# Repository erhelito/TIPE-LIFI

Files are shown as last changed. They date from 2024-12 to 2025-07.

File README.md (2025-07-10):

# TIPE LIFI
This is a school project in which we first created an operating communication system through light in ambient light conditions and without optic fiber. It includes multiple corrective systems, allowing us to use the system in a wide range of conditions. Then, we studied the performance of the system, in terms of length of transmission, thanks to the study of our laser dispersion.

For more information, please visit my website: https://www.erhelczc.wordpress.com

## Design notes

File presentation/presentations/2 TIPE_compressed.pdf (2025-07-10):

# COMMUNICATION PAR LASER À GRANDE DISTANCE

CAYZAC Erhel 32242

01

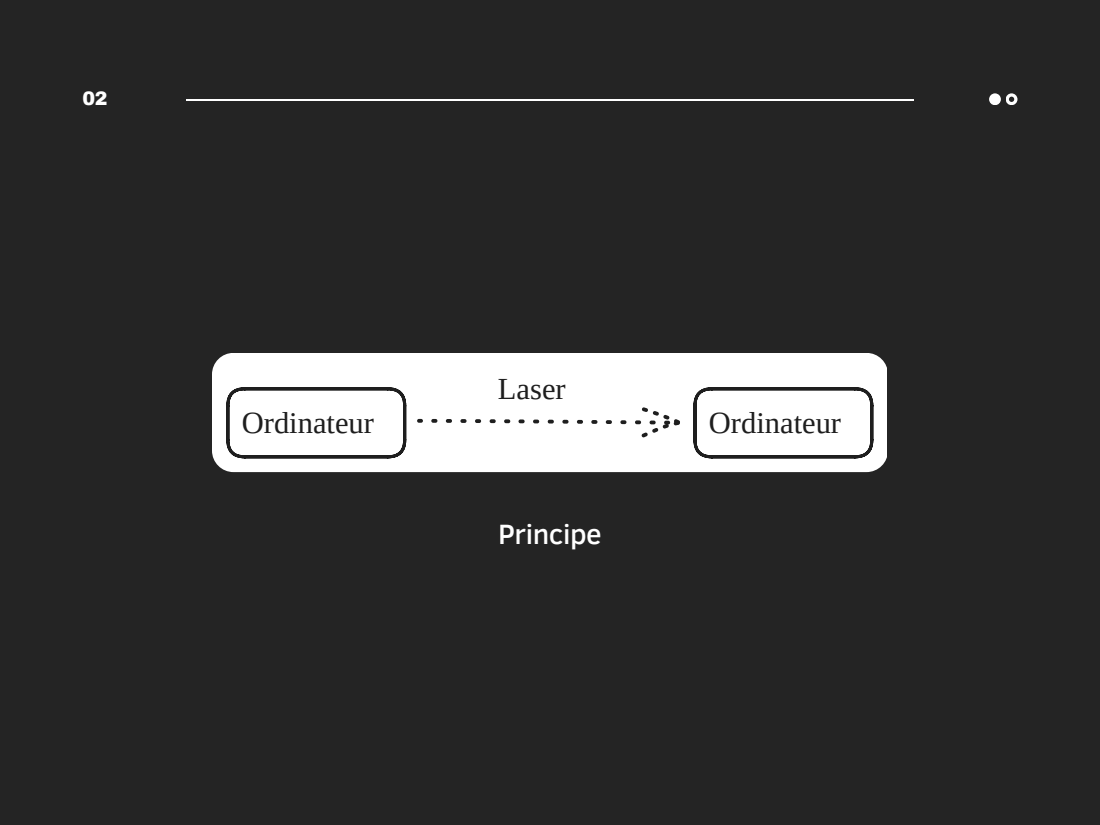
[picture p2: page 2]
Ordinateur; Laser; Principe

03

# POURQUOI ?

Haut débit de transmission Liaison sans fil sécurisée Lien analogique / numérique

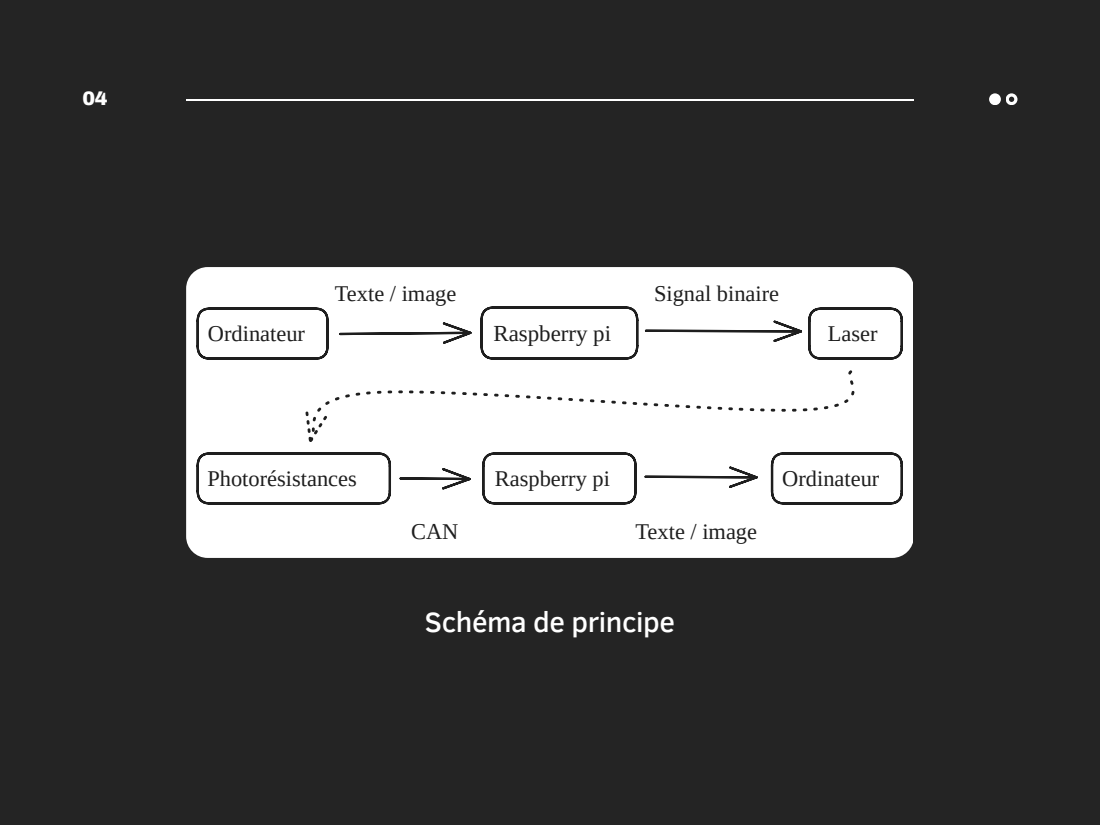
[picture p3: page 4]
Ordinateur; Texte / image; Signal binaire; CAN; Raspberry pi; Laser; Photorésistances

Schéma de principe

05

I PREMIER PROTOTYPE | PLAN

Électronique, transmission,
blocages, limitations

II AMÉLIORATION DU
MODÈLE
Capteurs, codes correcteurs, vitesse d’émission

III LIMITES, ÉTUDE
THÉORIQUE
Analyse théorique du projet proposé

06

# UN PREMIER PROTOTYPE

1.Émission
2.Protocole de communication 3.Réception
4.Problèmes rencontrés

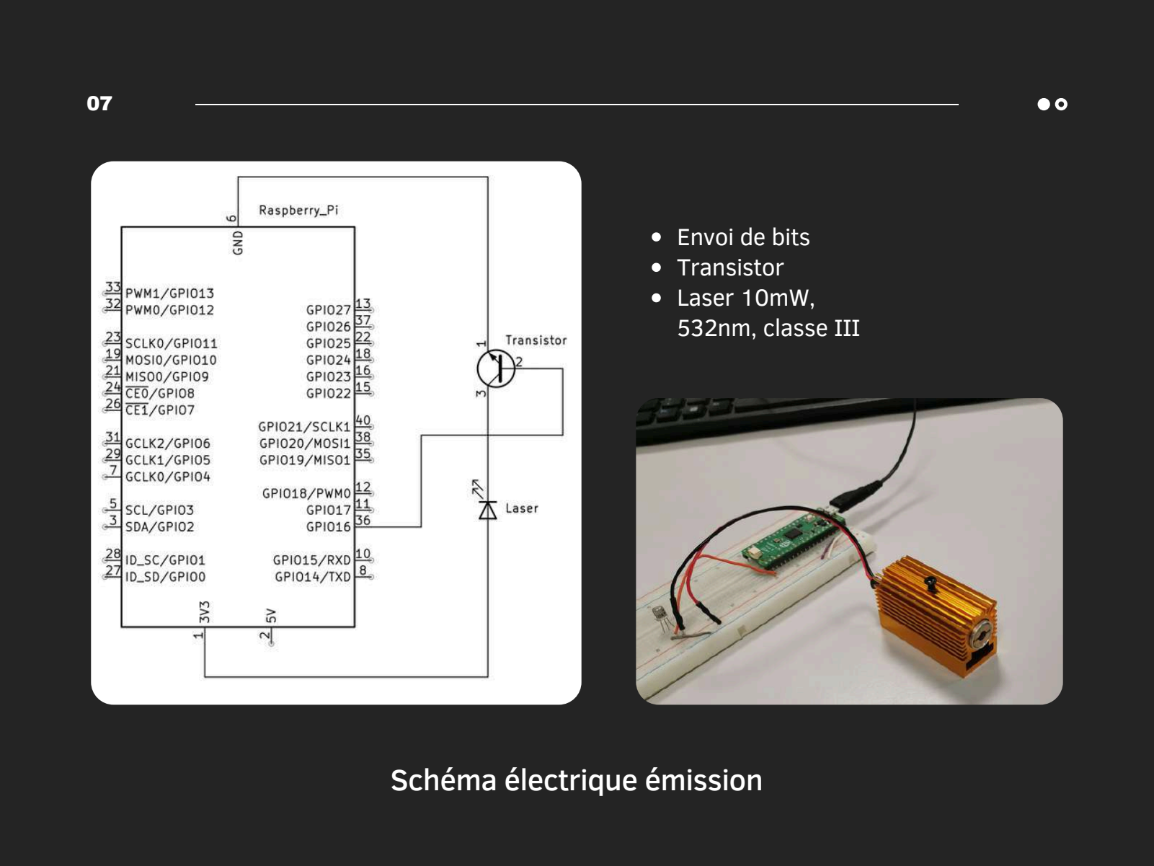
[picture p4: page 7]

07

Schéma électrique émission

Envoi de bits
Transistor
Laser 10mW,
532nm, classe III

08

Émission : “10110”

Réception : “...00010110000...”

### DÉTECTER L’ÉMISSION

Signal brut : “10110”

Émission : “1101101”

Réception : “...0001101101000...”

09

Schéma électrique réception

Diviseurs de tension
CAN
Comparaison
Seuil

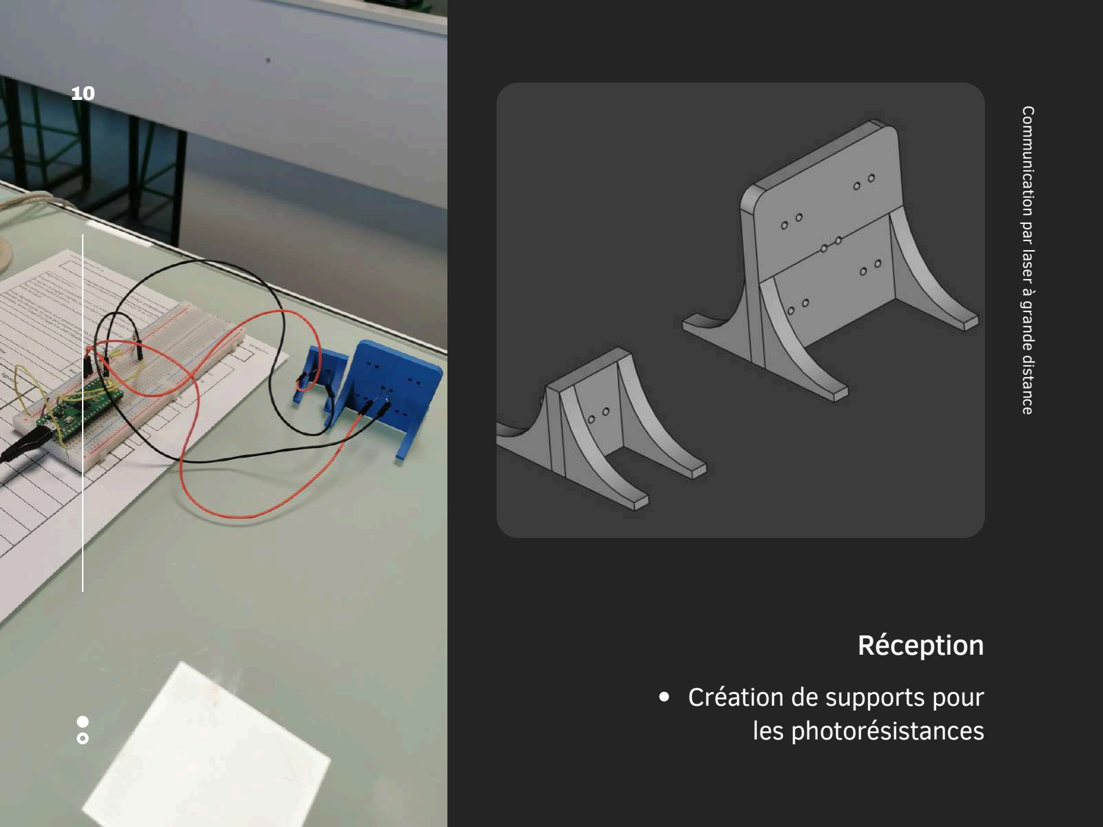
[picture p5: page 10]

1

0
Communication par laser à grande distance

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
r les photorésistances

11

# PREMIÈRES LIMITATIONS

Non adaptabilité (seuil)
Non linéarité (photorésistances) Manque de fiabilité (lenteur Raspberry)

12

# SECOND PROTOTYPE

1.Phototransistors
2.Traitement différé
3.Seuil variable
4.Gestion des erreurs

13

Schéma électrique réception

14

# SEUIL DE DÉTECTION

Comparaison des données
capteur
Partitionnement des données

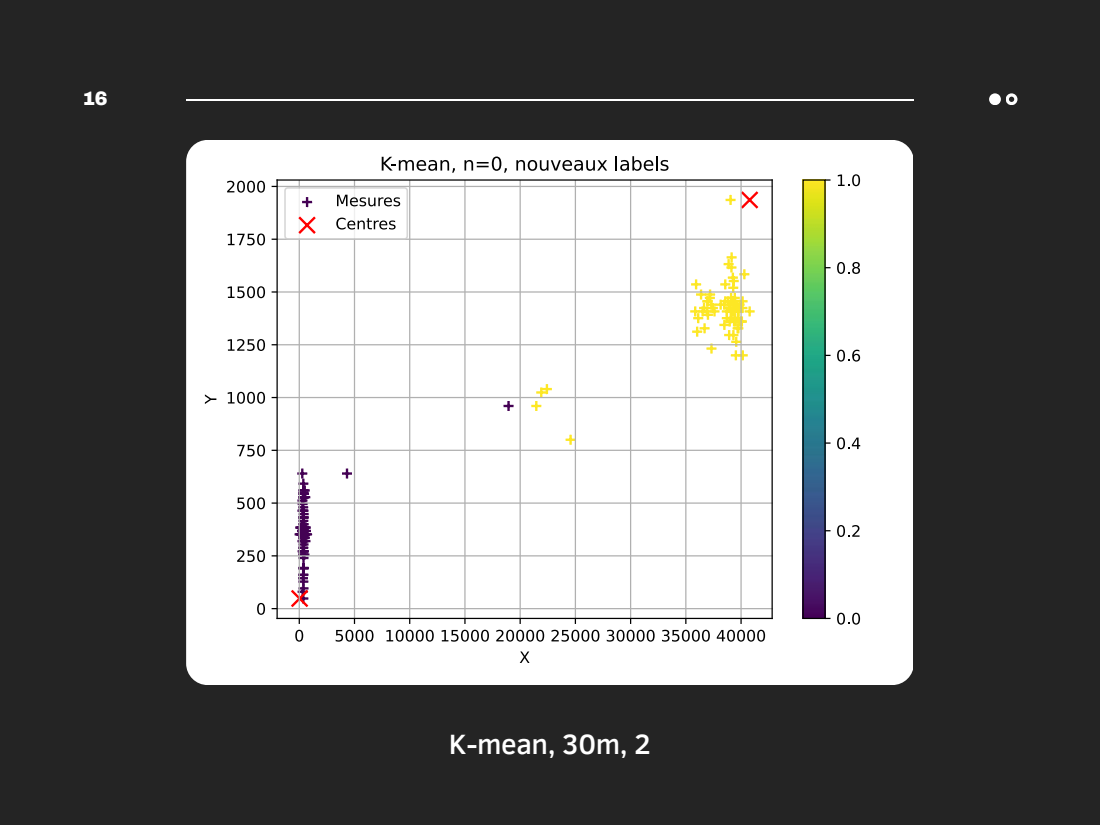
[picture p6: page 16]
K-mean, 30m, 2

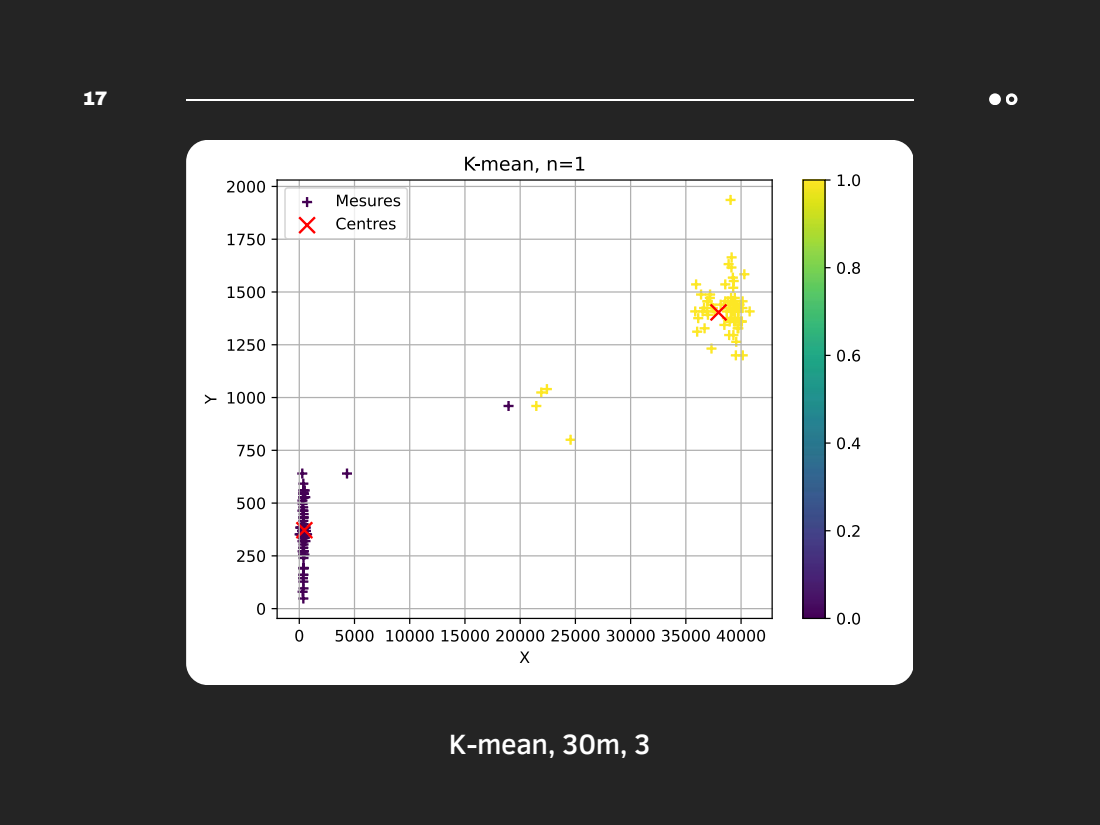
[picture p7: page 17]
K-mean, 30m, 3

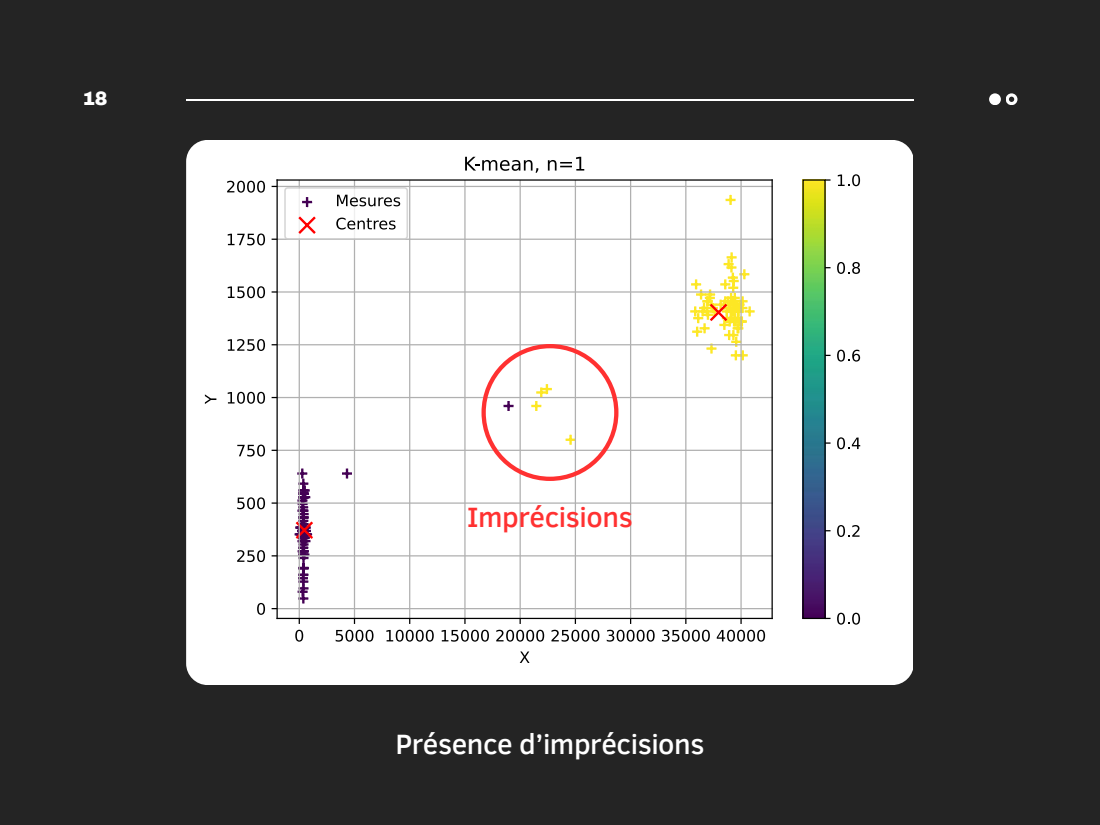
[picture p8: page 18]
Présence d’imprécisions; Imprécisions

19

# TRAITEMENT DES ERREURS

Critère de Shannon :
1.Filtrage par moyenne glissante

Code correcteur de Hamming : 1.Ajout de bits de parité
2.Vérification de la cohérence 3.Correction

1

9

Communication par laser à grande distance

21

# DIODE LASER

Modèle du faisceau gaussien Étude de l’évolution de l’irradiance lumineuse

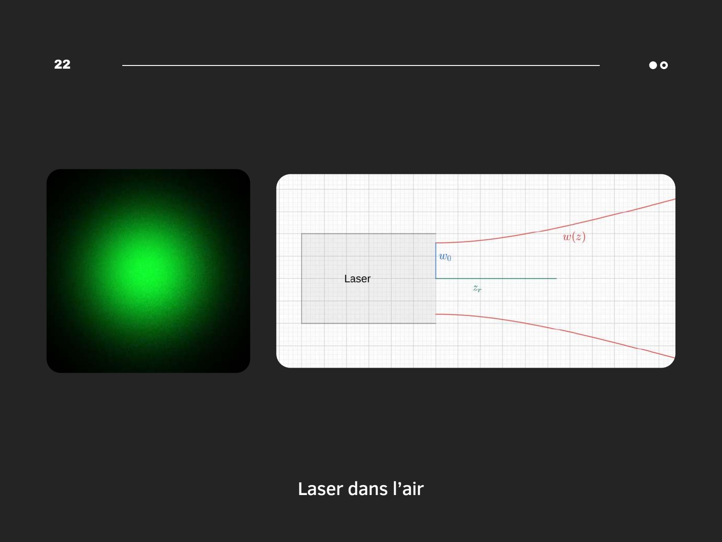
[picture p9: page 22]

Laser dans l’air

22

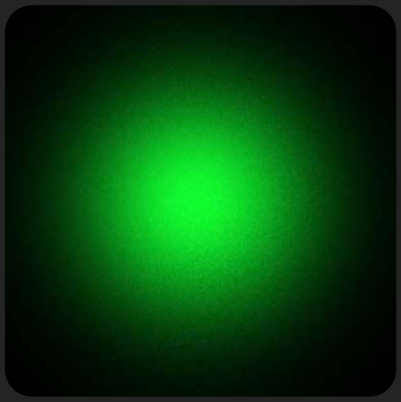
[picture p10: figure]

Irradiance du faisceau Gaussien

23

Divergence et longueur de Rayleigh

24

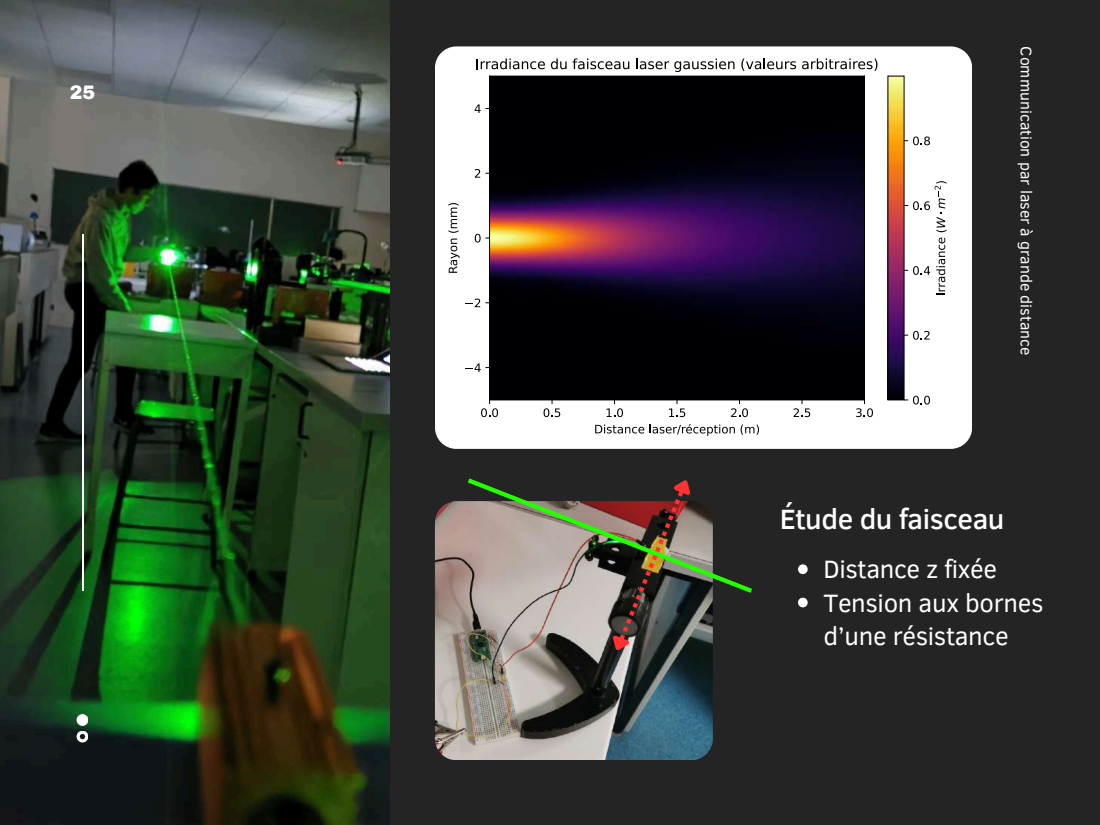
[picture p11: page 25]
fais; Dis; fix; sio; sis

Communication par laser à grande distance

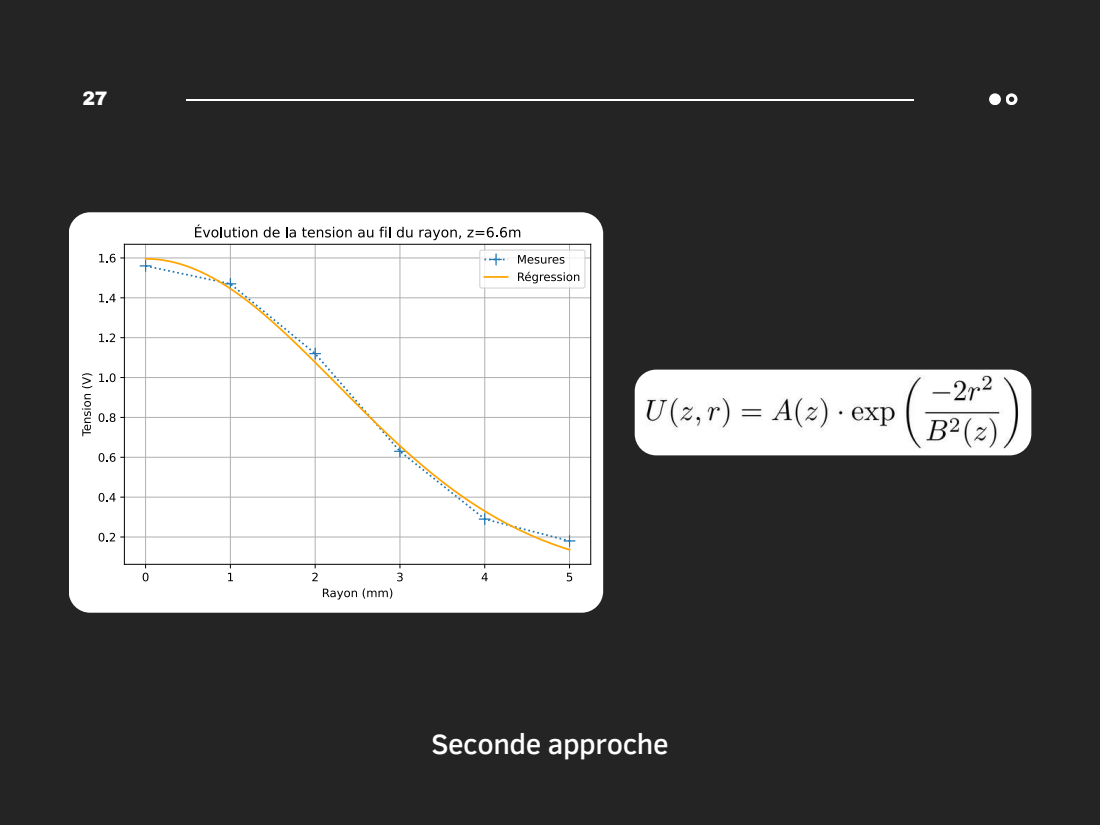
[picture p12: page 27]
Seconde approche

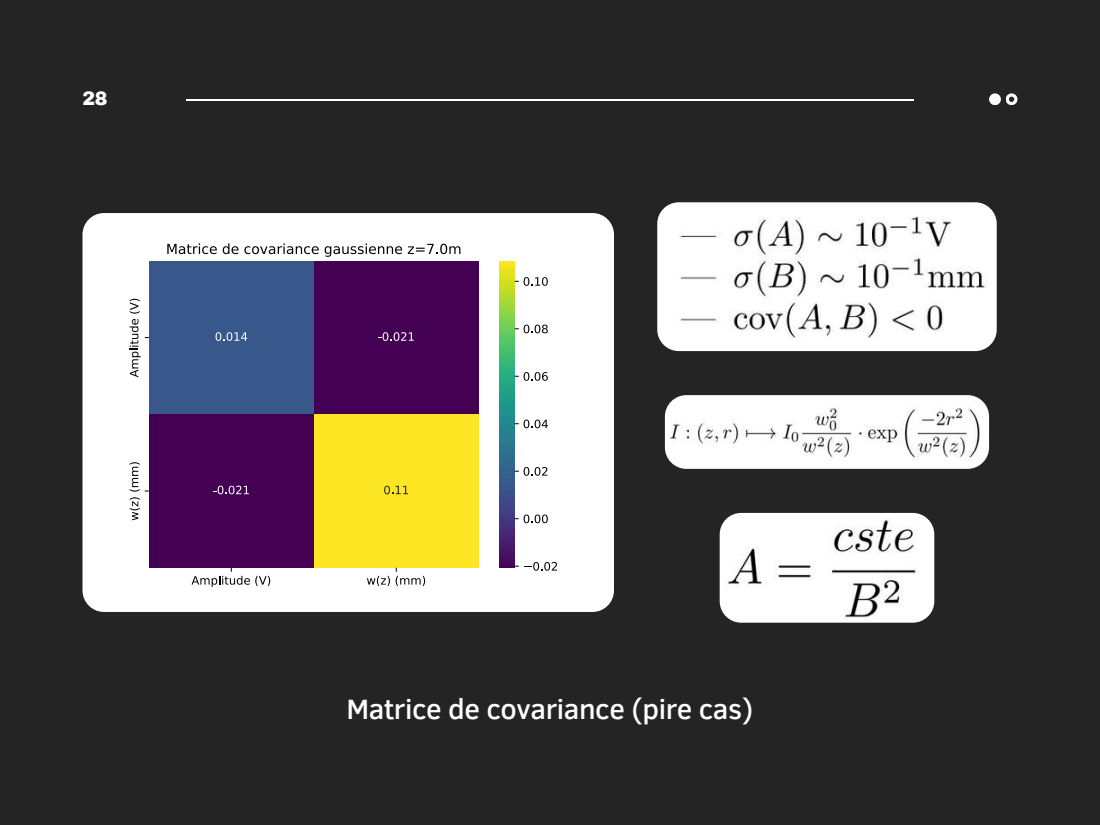
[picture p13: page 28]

Matrice de covariance (pire cas)

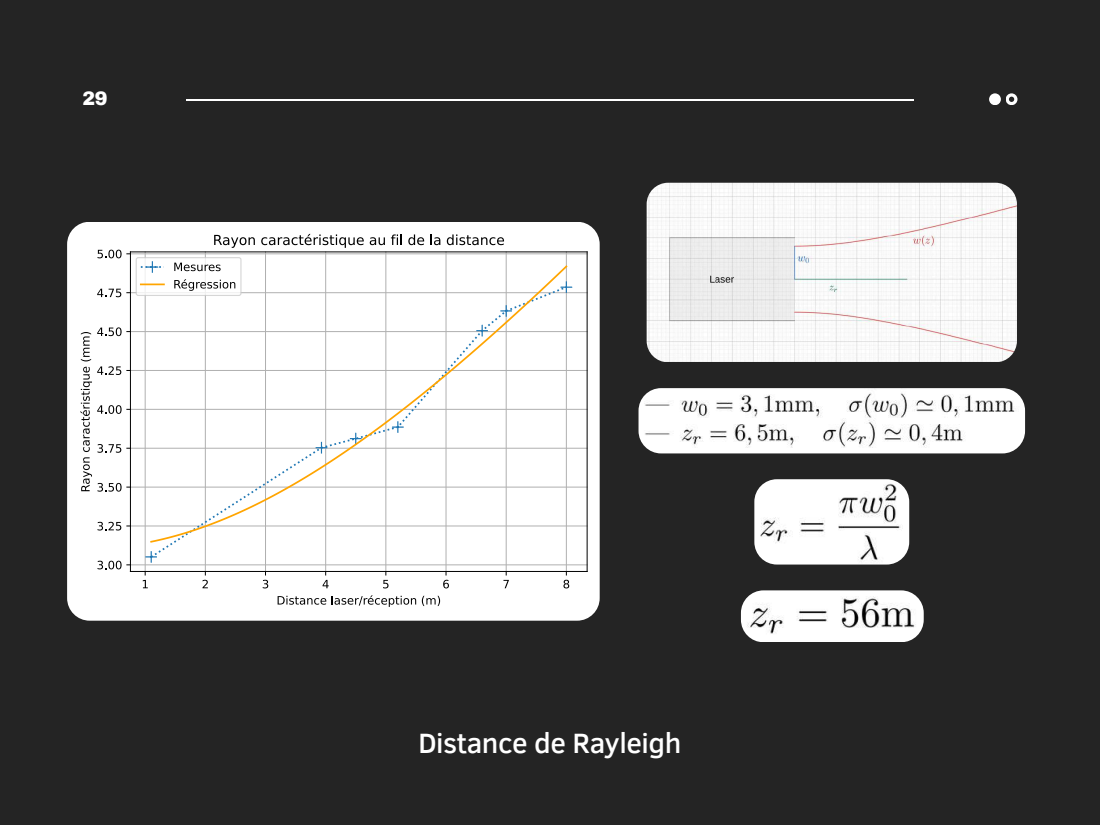
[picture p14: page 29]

Distance de Rayleigh

30

# CONCLUSION

Système fonctionnel
Adaptation à la luminosité Correction des erreurs
Débit peu élevé (Python)

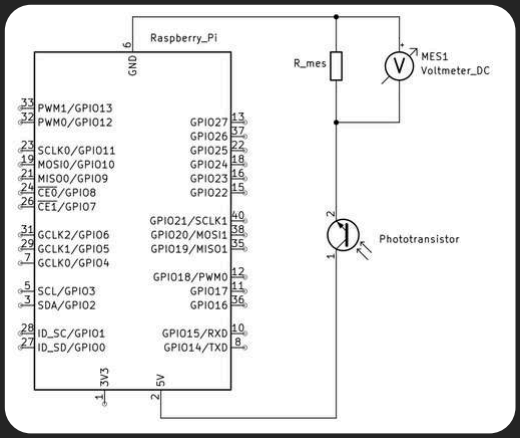
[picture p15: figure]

Annexe : Protocole faisceau Gaussien

31

32

# ANNEXE : PHOTORÉSISTANCE

Facile d’utilisation
Non linéaire

# Tracé de la caractéristique

PROTOCOLE :
Pont diviseur de
tension
Éclairement constant

33

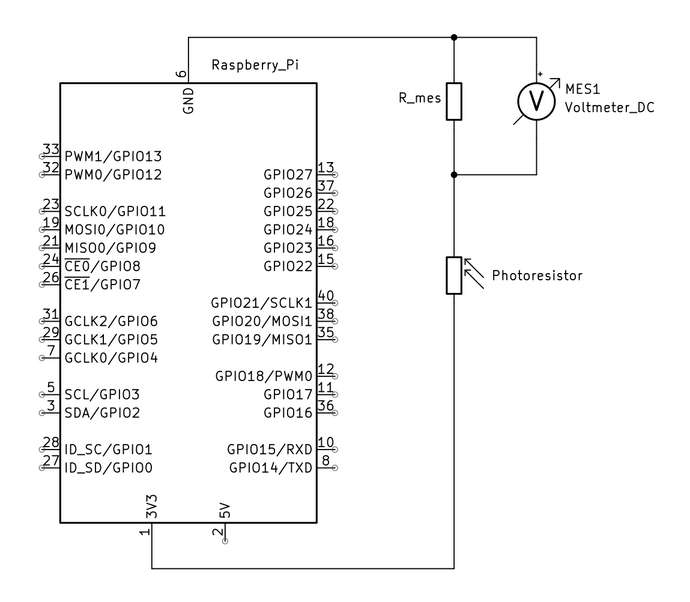
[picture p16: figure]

Schéma électrique

34

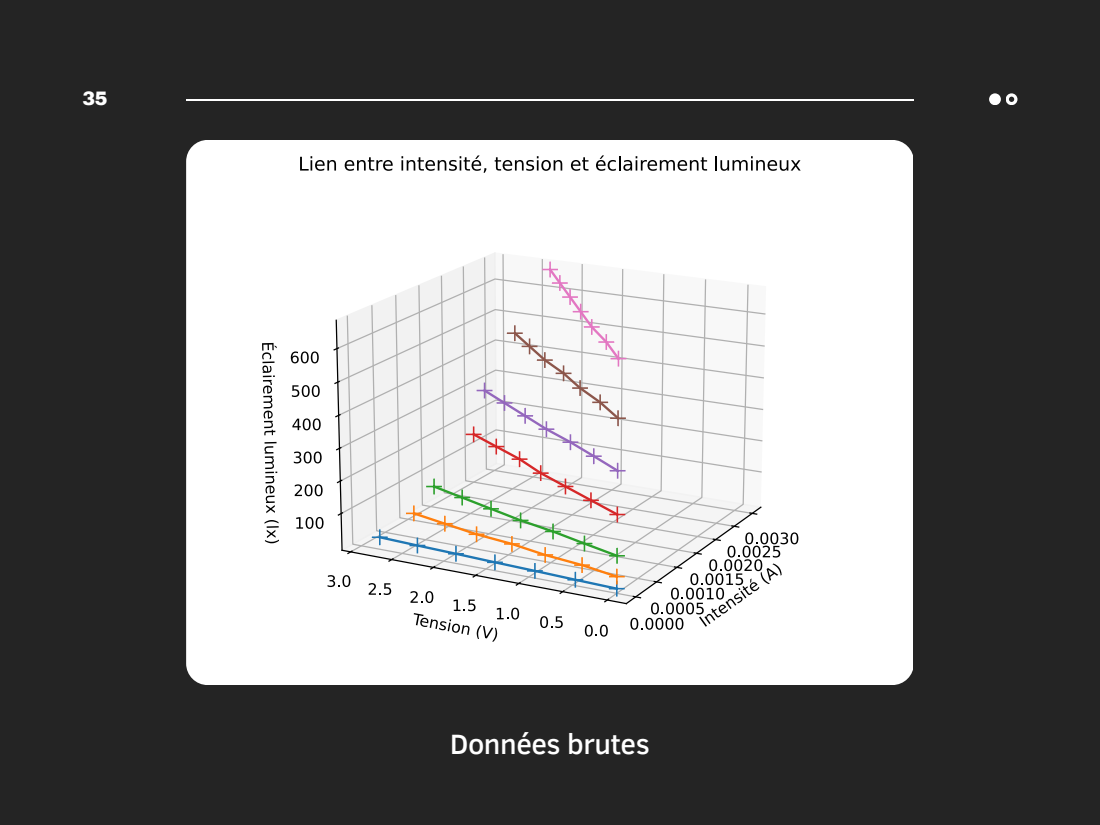
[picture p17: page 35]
Données brutes

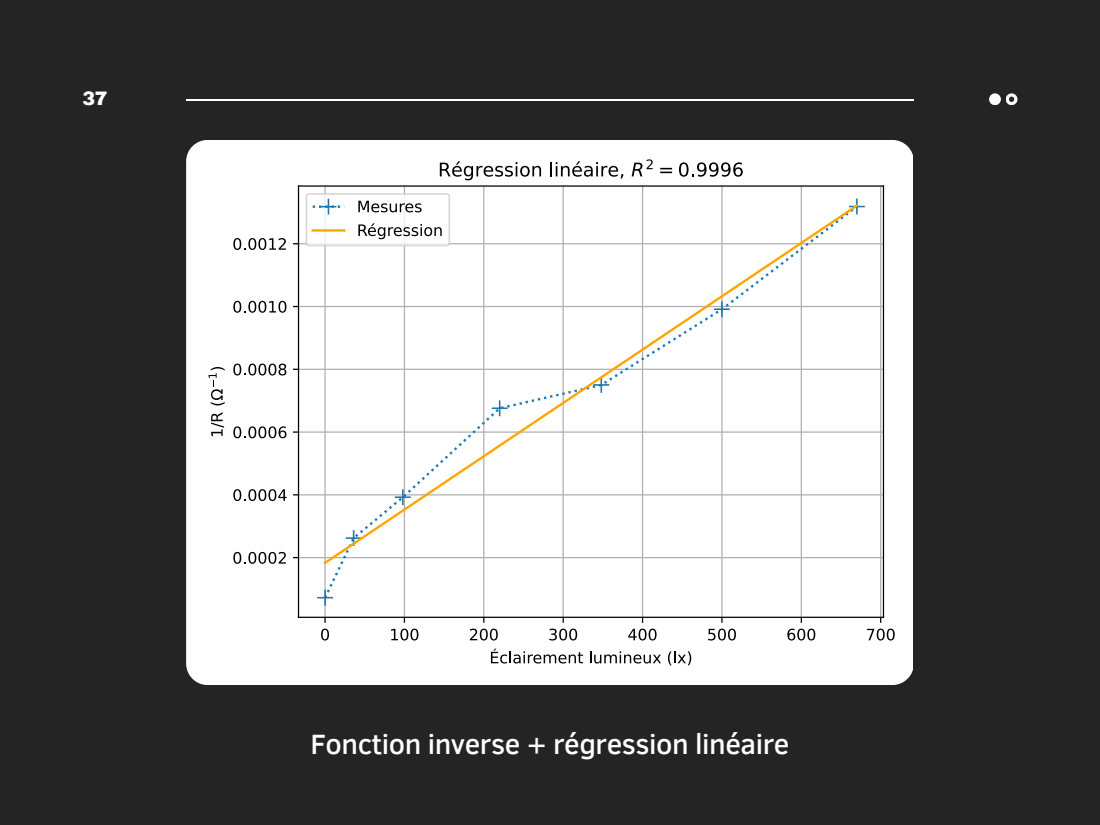
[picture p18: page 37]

Fonction inverse + régression linéaire

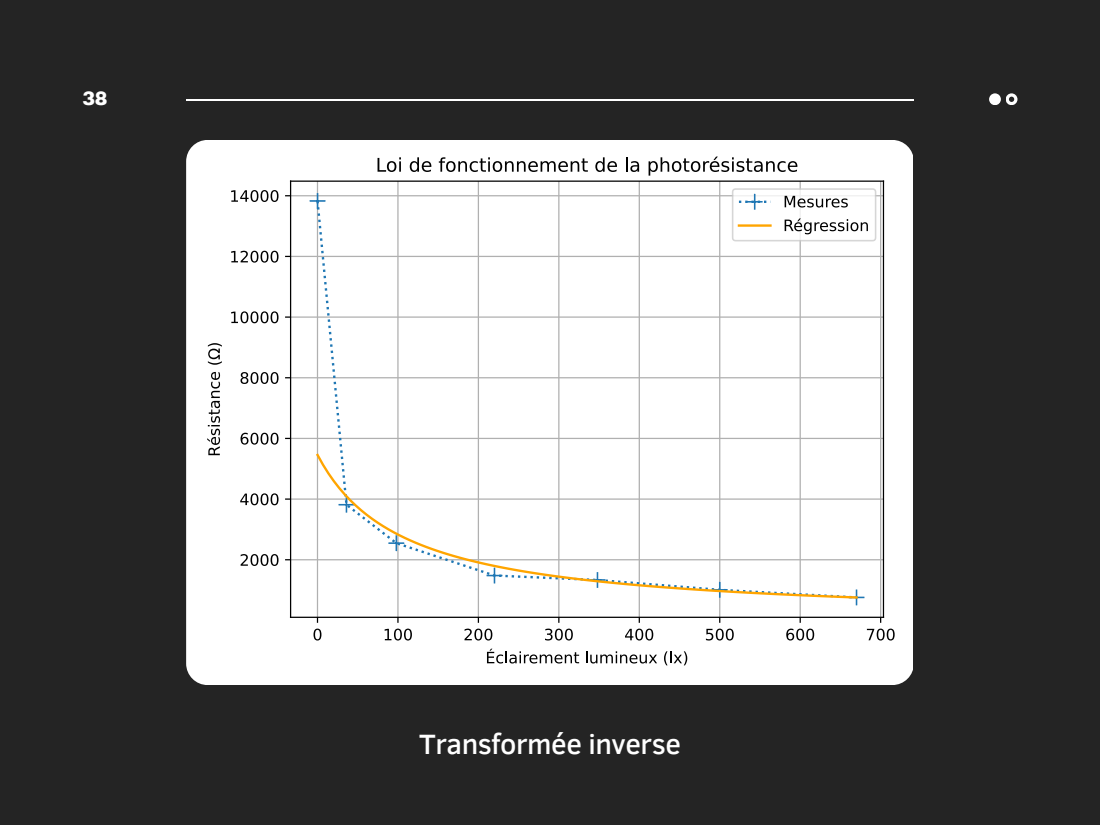
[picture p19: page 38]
Transformée inverse

39

# ANNEXE : HAMMING

Position | 7 | 6 | 5 | 4 | 3 | 2 | 1
Message | 1 | 0 | 0 | p2 | 1 | p1 | p0

40

Émission : “1001”

1.Détection des “1“
2.Encodage de leur position 3.Ajout de bits

### ENCODAGE

Position | 7 | 6 | 5 | 4 | 3 | 2 | 1
Message | 1 | 0 | 0 | p2 | 1 | p1 | p0

41

### ENCODAGE

Emplacements des 1 | 4 | 2 | 1
3 | 0 | 1 | 1
7 | 1 | 1 | 1

42

### ENCODAGE

Emplacements des 1 | 4 | 2 | 1
3 | 0 | 1 | 1
7 | 1 | 1 | 1
| p4 = 1 | p2 = 0 | p1 = 0

Émission : “1001100”

Position | 7 | 6 | 5 | 4 | 3 | 2 | 1
Message | 1 | 1 | 0 | 1 | 1 | 0 | 0

43

Émission : “1001100”
Réception : “1101100”

1.Détection des “1“
2.Encodage de leur position 3.Cohérence des bits de
parité

### DÉCODAGE

44

Emplacements des 1 | 4 | 2 | 1
3 | 0 | 1 | 1
4 | 1 | 0 | 0
6 | 1 | 1 | 0
7 | 1 | 1 | 1
Parité ? | x | x | v

Erreur détectée, position 2+4 = 6

### DÉCODAGE

Position | 7 | 6 | 5 | 4 | 3 | 2 | 1
Message envoyé | 1 | 0 | 0 | 1 | 1 | 0 | 0
Message reçu | 1 | 1 | 0 | 1 | 1 | 0 | 0
Message corrigé | 1 | 0 | 0 | 1 | 1 | 0 | 0

45

### DÉCODAGE

46

# ANNEXES : CODES

Annexe : Émission, 1

47

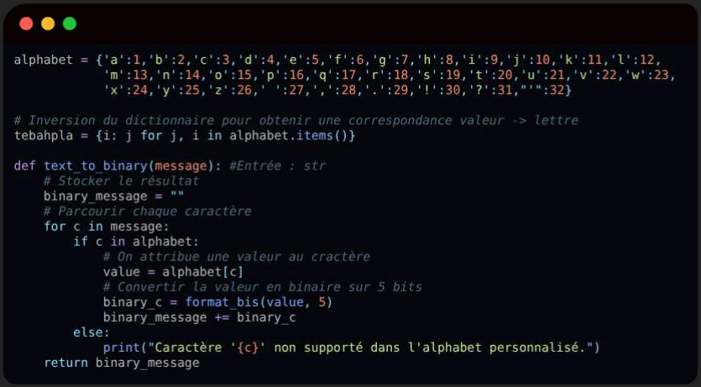
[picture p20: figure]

Annexe : Émission, 2

48

Annexe : Émission, 3

49

Annexe : Émission, 4

50

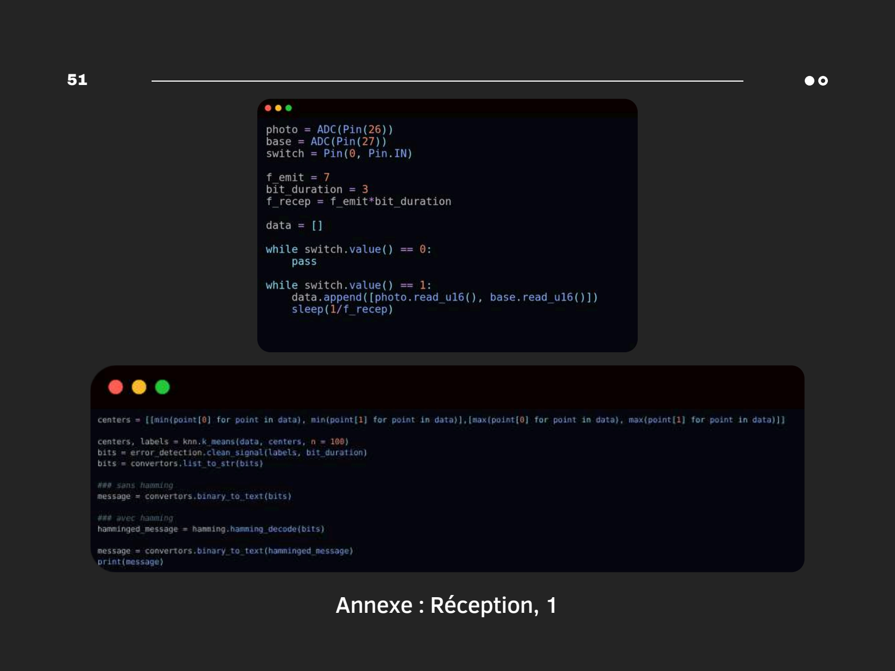
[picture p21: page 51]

Annexe : Réception, 1

51

Annexe : Réception, 2

52

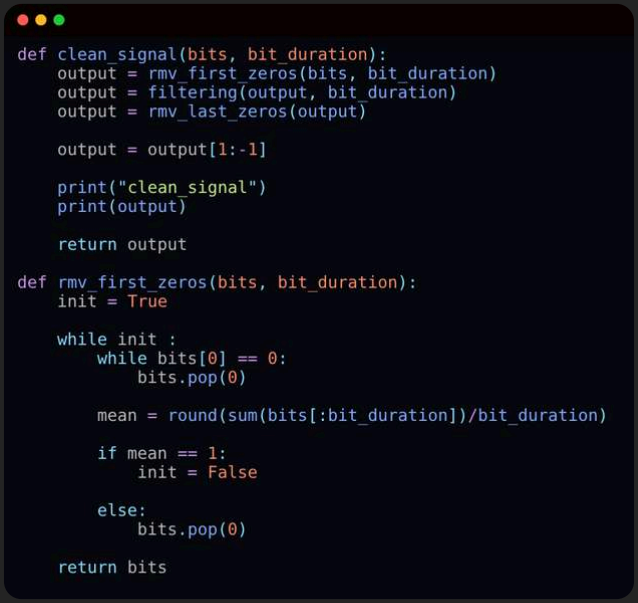
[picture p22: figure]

Annexe : Réception, 3

53

Annexe : Réception, 4

54

Annexe : Réception, 5

55

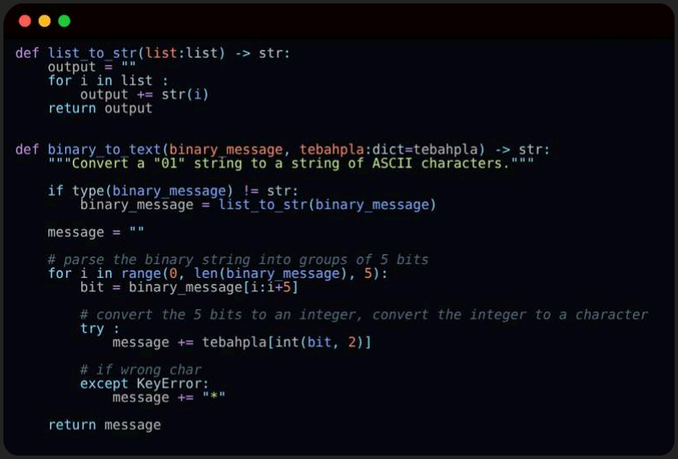
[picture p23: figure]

Annexe : Réception, 6

56

Annexe : Topographie de l’irradiance

57

Annexe : Caractéristique laser, 1

58

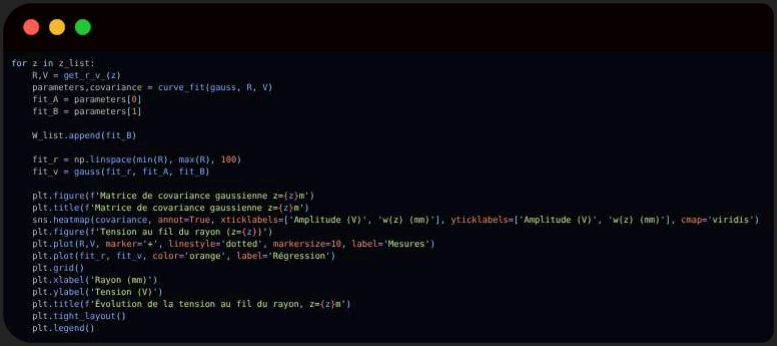
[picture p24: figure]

Annexe : Caractéristique laser, 2

59

Annexe : Caractéristique laser, 3

60

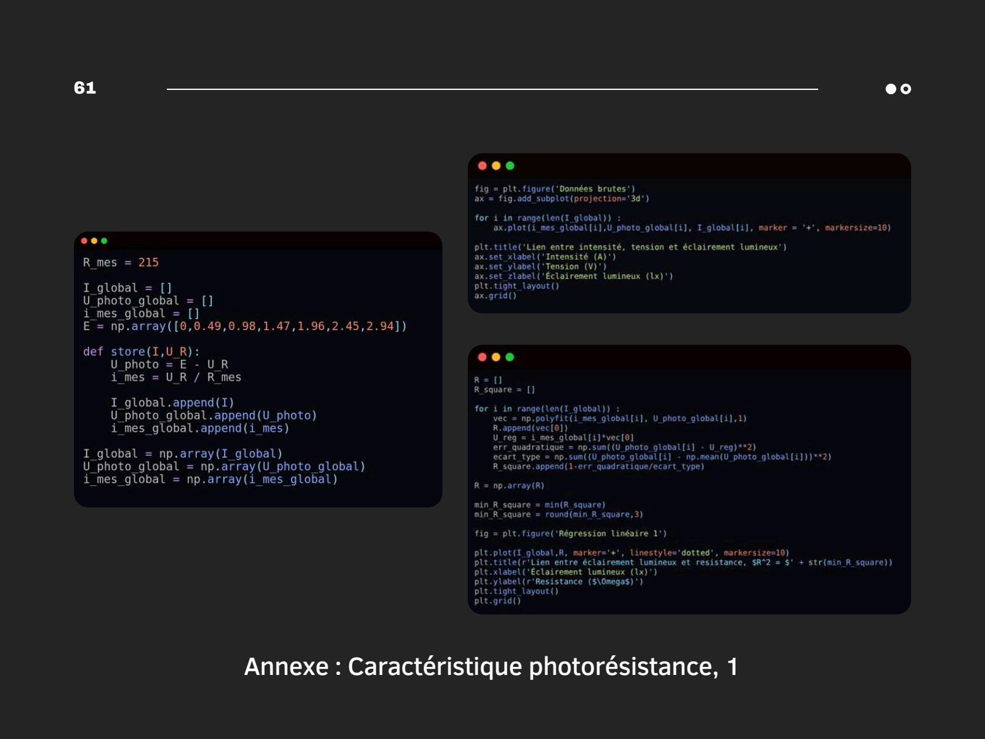
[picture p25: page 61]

Annexe : Caractéristique photorésistance, 1

61

Annexe : Caractéristique photorésistance, 2

62

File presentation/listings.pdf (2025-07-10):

## Communication par laser à grande distance, listings de code

## Table des matières

1 Émission | 1
2 Réception (code principal) | 3
3 Réception (K-mean) | 4
4 Réception (Traitement) | 5
5 Réception (Hamming) | 6
6 Réception (Conversion) | 8
7 Topographie de l’irradiance | 9
8 Caractérisation du faisceau Gaussien : | 10
9 Caractérisation des photorésistances : | 11

## 1 Émission

1 from machine import Pin , PWM, ADC # t y p e : i g n o r e 2 from time import s l e e p

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

b i n a i r e = "0" + b i n a i r e

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

b i n a i r e = b i n a i r e [−nb_bits : ]

return b i n a i r e

l e d = Pin ( ’LED ’ , Pin .OUT)
l a s e r = Pin (16 , Pin .OUT)

34 # Al p h abe t p e r s o n n a l i s é codé s u r 32 c a r a c t è r e s ( chacun pouvan t a i n s i ê t r e codé s u r 5 b i t s )
al p ha b e t = { ’ a ’ : 1 , ’ b ’ : 2 , ’ c ’ : 3 , ’ d ’ : 4 , ’ e ’ : 5 , ’ f ’ : 6 , ’ g ’ : 7 , ’ h ’ : 8 , ’ i ’ : 9 , ’ j ’ : 1 0 , ’ k ’ : 1 1 , ’ l ’ : 1 2 ,
’m’ : 1 3 , ’ n ’ : 1 4 , ’ o ’ : 1 5 , ’ p ’ : 1 6 , ’ q ’ : 1 7 , ’ r ’ : 1 8 , ’ s ’ : 1 9 , ’ t ’ : 2 0 , ’ u ’ : 2 1 , ’ v ’ : 2 2 , ’w ’ : 2 3 ,
’ x ’ : 2 4 , ’ y ’ : 2 5 , ’ z ’ : 2 6 , ’ ’ : 2 7 , ’ , ’ : 2 8 , ’ . ’ : 2 9 , ’ ! ’ : 3 0 , ’ ? ’ : 3 1 , " ’ " :3 2}

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

42 def text_to_binary ( message ) : #En trée : s t r
# S t o c k e r l e r é s u l t a t

binary_message = ""
# P a rc o u r i r chaque c a r a c t è r e for c in message :

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

#Donc aucun de s b i t s ne s e r a commun à x e t x−1 donc " l ’

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

90 def emi s sio n ( bina ry , f ) : bi na r y2="1"+str ( bi na r y )+"1" for x in bi na r y2 :
i f x == "1" :
l a s e r . high ( )
s l e e p (1/ f )
l a s e r . low ( )
e l s e :
s l e e p (1/ f )

100 def t e x t_ to_lig h t ( message , f ) :
return ( emi s sio n ( text_to_binary ( message ) , f ) )

103 def text_to_light_hamming ( message , f ) : return ( emi s sio n ( hamming_encode ( text_to_binary ( message ) ) , f ) )

## 2 Réception (code principal)

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

6 from time import s l e e p 7
8 photo = ADC( Pin ( 26 ) )
9 ba se = ADC( Pin ( 27 ) )
10 swi t c h = Pin ( 0 , Pin . IN ) 11
12 f_emit = 7
13 bi t_ d u ra tio n = 3
14 f_ recep = f_emit ∗ bi t_ d u ra tio n 15
16 data = [ ]
17
18 while swi t c h . val u e ( ) == 0 :
19 | pass
20
21 while swi t c h . val u e ( ) == 1 :
22 | data . append ( [ photo . read_u16 ( ) , ba se . read_u16 ( ) ] )
23 | s l e e p (1/ f_ recep )
24
25 | c e n t e r s = [ [ min( poi n t [ 0 ] for poi n t in data ) , min( poi n t [ 1 ] for poi n t in
| data ) ] , [max( poi n t [ 0 ] for poi n t in data ) , max( poi n t [ 1 ] for poi n t in
| data ) ] ]
26
27 | c e n t e r s , l a b e l s = kmean . k_means ( data , c e n t e r s , n = 100 )
28 | b i t s = e r r o r _ d e t e c ti o n . cl e a n _ si g n al ( l a b e l s , bi t_ d u ra tio n )
29 | b i t s = c o n v e r t o r s . li s t _ t o _ s t r ( b i t s )
30
31 ### sans hamming
32 message = c o n v e r t o r s . binary_to_text ( b i t s )
33
34 ### avec hamming
35 hamminged_message = hamming . hamming_decode ( b i t s )
36
37 message = c o n v e r t o r s . binary_to_text ( hamminged_message ) 38 pr int ( message )

## 3 Réception (K-mean)

1 from math import s q r t
2
3 def di s t a n c e ( p1 , p2 ) :
4 | return s q r t ( ( p1 [ 0 ] − p2 [ 0 ] ) ∗∗ 2 + ( p1 [ 1 ] − p2 [ 1 ] ) ∗∗ 2 )
5
6 def k_means ( data , c e n t e r s , n=100) :
7 | n_points = len ( data )
8 | n_ cl u s t e r s = len ( c e n t e r s )
9
10 | l a b e l s = [ 0 ] ∗ n_points

for _ in range ( n ) :
# u p d a te l a b e l s

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

# u p d a te c l u s t e r s

new_centers = [ ]
for k in range ( n_ cl u s t e r s ) :
cl u s t e r _ p oi n t s = [ data [ i ] for i in range ( n_points ) i f new_labels [ i ] == k ]
i f cl u s t e r _ p oi n t s != [ ] : # f o r no t empty c l u s t e r s
mean_x = sum( poi n t [ 0 ] for poi n t in cl u s t e r _ p oi n t s ) / len ( cl u s t e r _ p oi n t s )
mean_y = sum( poi n t [ 1 ] for poi n t in cl u s t e r _ p oi n t s ) / len ( cl u s t e r _ p oi n t s )
new_centers . append ( [ mean_x , mean_y ] )

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

# c heck f o r c onve rgence

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

pr int ( " l a b e l s " )
pr int ( l a b e l s )

return c e n t e r s , l a b e l s

## 4 Réception (Traitement)

1 def cl e a n _ si g n al ( bi t s , bi t_ d u ra tio n ) :
output = rm v_ fi r s t_ze ro s ( bi t s , bi t_ d u ra tio n ) output = f i l t e r i n g ( output , bi t_ d u ra tio n ) output = rmv_last_zeros ( output )

output = output [1: −1]

pr int ( " cl e a n _ si g n al " ) pr int ( output )

return output

13 def rm v_ fi r s t_ze ro s ( bi t s , bi t_ d u ra tio n ) : i n i t = True

while i n i t :
while b i t s [ 0 ] == 0 :
b i t s . pop ( 0 )

mean = round(sum( b i t s [ : bi t_ d u ra tio n ] ) / bi t_ d u ra tio n )

i f mean == 1 :
i n i t = Fal s e

e l s e :
b i t s . pop ( 0 )

return b i t s

30 def f i l t e r i n g ( bi t s , bi t_ d u ra tio n ) : n = len ( b i t s )
g roup s = [ b i t s [ i : i+bi t_ d u ra tio n ] for i in range ( 0 , n , bi t_ d u ra tio n ) ] output = [ ]

for group in g roup s :
mean = round(sum( group ) / bi t_ d u ra tio n ) output . append (mean )

return output

41 def f i n t e r i n g 2 ( bi t s , bi t_ d u ra tio n ) : n = len ( b i t s )
g roup s = [ b i t s [ i : i+bi t_ d u ra tio n ] for i in range ( 0 , n , bi t_ d u ra tio n ) ] output = [ ]

for group in g roup s :
mean = round(sum( group [ 1: −1] ) / ( bi t_du ra tion −2) ) output . append (mean )

return output

52 def rmv_last_zeros ( b i t s ) : while b i t s [ −1] == 0 : b i t s . pop (−1)

return b i t s

## 5 Réception (Hamming)

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

b i n a i r e = "0" + b i n a i r e

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

b i n a i r e = b i n a i r e [−nb_bits : ]

return b i n a i r e

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

## 6 Réception (Conversion)

1 # p e r s o n a l i z e d a l p h a b e t coded on 32 c h a r a c t e r s ( each c h a r a c t e r can be coded on 5 b i t s )
al p ha b e t = { ’ a ’ : 1 , ’ b ’ : 2 , ’ c ’ : 3 , ’ d ’ : 4 , ’ e ’ : 5 , ’ f ’ : 6 , ’ g ’ : 7 , ’ h ’ : 8 , ’ i ’ : 9 , ’ j ’ : 1 0 , ’ k ’ : 1 1 , ’ l ’ : 1 2 ,
’m’ : 1 3 , ’ n ’ : 1 4 , ’ o ’ : 1 5 , ’ p ’ : 1 6 , ’ q ’ : 1 7 , ’ r ’ : 1 8 , ’ s ’ : 1 9 , ’ t ’ : 2 0 , ’ u ’ : 2 1 , ’ v ’ : 2 2 , ’w ’ : 2 3 ,
’ x ’ : 2 4 , ’ y ’ : 2 5 , ’ z ’ : 2 6 , ’ ’ : 2 7 , ’ , ’ : 2 8 , ’ . ’ : 2 9 , ’ ! ’ : 3 0 , ’ ? ’ : 3 1 , " ’ " :3 2}

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

9 def li s t _ t o _ s t r ( l i s t : l i s t ) −> str :
output = ""
for i in l i s t :
output += str ( i )
return output

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

i f type ( binary_message ) != str :
binary_message = li s t _ t o _ s t r ( binary_message )

message = ""

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

## 7 Topographie de l’irradiance

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

34 p l t . show ( )

## 8 Caractérisation du faisceau Gaussien :

1 import numpy a s np
2 import m a t pl o tli b . p y plo t a s p l t
3 import s q l i t e 3
4 from s ci p y . o p timi z e import c u r v e_ fi t 5 import seabo rn a s s n s
6
7 def gau s s ( x , A, B) :
8 | y = A∗np . exp (−2∗x ∗∗2/ (B∗∗2 ) )
9 | return y
10
11 def di v ( x ,A,B) :
12 | y = A∗np . s q r t (1+(x/B) ∗∗2 )
13 | return y
14
15 def get_r_v ( z ) :
16 | g loba l cu r
17 | cu r . e x e c u t e ( f ’SELECT data . Radius , data . Vol tage FROM data WHERE data .
| di s t a n c e = { z } AND data . r a di u s >= {0} ORDER BY data . Radius ’ )
18 | rows = cu r . f e t c h a l l ( )
19 | r = np . a r ra y ( [ row [ 0 ] for row in rows ] )
20 | v = np . a r ra y ( [ row [ 1 ] for row in rows ] )
21 | return np . a r ra y ( r ) , np . a r ra y ( v )
22
23 conn = s q l i t e 3 . connec t ( ’V2/ data2 . db ’ )
24 cu r = conn . c u r s o r ( )
25
26 | z _ l i s t = cu r . e x e c u t e ( ’SELECT DISTINCT data . di s t a n c e FROM data ORDER BY
| data . di s t a n c e ’ ) . f e t c h a l l ( )
27 | z _ l i s t = [ z [ 0 ] for z in z _ l i s t ]
28 W_list = [ ]
29
30 for z in z _ l i s t :
31 | R,V = get_r_v ( z )
32 | parameters , c o v a ri a n c e = c u r v e_ fi t ( gauss , R, V)
33 | fit_A = pa rame te r s [ 0 ]
34 | fit_B = pa rame te r s [ 1 ]
35
36 | W_list . append ( fit_B )
37
38 | f i t _ r = np . l i n s p a c e (min(R) , max(R) , 100 )
39 | fi t_ v = gau s s ( fi t_ r , fit_A , fit_B )
40
41 | p l t . f i g u r e ( f ’ Ma t rice de c o v a ri a n c e g a u s si e n n e z={z }m’ )
42 | p l t . t i t l e ( f ’ Ma t rice de c o v a ri a n c e g a u s si e n n e z={z }m’ )

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

z _li s t , W_list = np . a r ra y ( z _ l i s t ) , np . a r ra y (W_list )

56 parameters , c o v a ri a n c e = c u r v e_ fi t ( div , z_li s t , W_list ) 57 fit_A = pa rame te r s [ 0 ]
58 fit_B = pa rame te r s [ 1 ]

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

64 pr int ( f ’W0 = { fit_A } , z r = { fit_B } ’ )

fi t _ z = np . l i n s p a c e (min( z _ l i s t ) , max( z _ l i s t ) , 100 ) 67 fit_w = di v ( fi t_ z , fit_A , fit_B )

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

## 9 Caractérisation des photorésistances :

1 import numpy a s np
2 import m a t pl o tli b . p y plo t a s p l t

4 # r e s de mesure
5 R_mes = 215
6
7 I_glo bal = [ ]
8 U_photo_global = [ ]
9 i_mes_global = [ ]
10 E = np . a r ra y ( [ 0 , 0 . 4 9 , 0 . 9 8 , 1 . 4 7 , 1 . 9 6 , 2 . 4 5 , 2 . 9 4 ] ) 11
12 def s t o r e ( I ,U_R) :
13 | U_photo = E − U_R
14 | i_mes = U_R / R_mes
15
16 | I_glo bal . append ( I )
17 | U_photo_global . append ( U_photo )
18 | i_mes_global . append ( i_mes )
19
20 I_glo bal = np . a r ra y ( I_glo bal )
21 U_photo_global = np . a r ra y ( U_photo_global ) 22 i_mes_global = np . a r ra y ( i_mes_global )
23
24 ### FIRST PLOT ###
25 f i g = p l t . f i g u r e ( ’ Données b r u t e s ’ )
26 ax = f i g . add_subplot ( p r o j e c t i o n=’ 3d ’ )
27
28 for i in range (len ( I_glo bal ) ) :
29 | ax . pl o t ( i_mes_global [ i ] , U_photo_global [ i ] , I_glo bal [ i ] , marker = ’+’ ,
| ma r k e r si z e =10)
30
31 p l t . t i t l e ( ’ Lien e n t r e i n t e n s i t é , t e n si o n e t é cl ai r em e n t lumineux ’ )
32 ax . s e t_ xl a b el ( ’ I n t e n s i t é (A) ’ )
33 ax . s e t_ yl a b el ( ’ Tension (V) ’ )
34 ax . s e t _ zl a b el ( ’ É clai r em e n t lumineux ( l x ) ’ )
35 p l t . tig h t_la yo u t ( )
36 ax . g ri d ( )
37
38 ### LINEAR REGRESSION ### 39 R = [ ]
40 R_square = [ ]
41
42 for i in range (len ( I_glo bal ) ) :
43 | vec = np . p o l y f i t ( i_mes_global [ i ] , U_photo_global [ i ] , 1 )
44 | R. append ( vec [ 0 ] )
45 | U_reg = i_mes_global [ i ] ∗ vec [ 0 ]
46 | e r r_ q ua d ra ti qu e = np .sum( ( U_photo_global [ i ] − U_reg ) ∗∗2 )
47 | eca r t_ type = np .sum( ( U_photo_global [ i ] − np . mean ( U_photo_global [ i ] ) )
| ∗∗2 )
48 | R_square . append(1−e r r_ q ua d ra ti qu e / eca r t_ type )
49
50 R = np . a r ra y (R)
51
52 min_R_square = min( R_square )
53 min_R_square = round(min_R_square , 3 )

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

64 ### LOI PHOTORESISTANCE ###
65 new_R = 1/R

67 vec = np . p o l y f i t ( I_global , new_R, 1 )
I_li n = np . l i n s p a c e (min( I_glo bal ) ,max( I_glo bal ) ,100 )
r eg = vec [ 0 ] ∗ I_li n + vec [ 1 ]

e r r_ quad ra ti q ue = np .sum( ( U_photo_global [ i ] − U_reg ) ∗∗2 )
72 eca r t_ type = np .sum( ( U_photo_global [ i ] − np . mean ( U_photo_global [ i ] ) ) ∗∗2 )

74 R_square = (1−e r r_ q ua d ra ti qu e / eca r t_ type )
75 R_square = round( R_square , 4 )

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

87 R_reg = 1/ r eg

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

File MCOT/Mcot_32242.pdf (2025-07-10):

32242 CAYZAC Erhel

## Étude de la communication par laser à grande distance

Au collège, mon professeur de technologie nous avait parlé d'un nouveau système de communication par lumière : le Li-Fi. Passionné par les sciences numériques, je m'étais alors demandé comment de la simple lumière pouvait transporter de l'information. C'est la question à laquelle j'essaie de répondre au travers de ce TIPE.

Il s’agit de concevoir et de mettre en œuvre un système capable de transmettre des images ou un signal sonore entre deux bâtiments séparés d’une centaine de mètres, en utilisant un signal lumineux comme support de transmission. Pour cela, on convertira un signal numérique en signal électrique puis lumineux.

Ce TIPE fait l'objet d'un travail de groupe.
Liste des membres du groupe :
- PERROT Raphaël
Positionnement thématique (ÉTAPE 1) :
- SCIENCES INDUSTRIELLES (Traitement du Signal)
- PHYSIQUE (Physique Ondulatoire)
- INFORMATIQUE (Informatique pratique)

Mots-clés (ÉTAPE 1) :

Mots-clés (en français)
Communication sans fil
Conversion Analogique-Numérique (CAN) Encodage de l’information
Algorithme K-nn
Laser

Mots-clés (en anglais)
Wireless communication
Analog-to-Digital Conversion (ADC) Information encoding
K-nn algorithm
Laser

Bibliographie commentée

Les technologies de communication sans fil ont connu une évolution rapide ces dernières années, propulsées par l’augmentation du nombre de dispositifs connectés et la nécessité de répondre à une demande croissante de données à haut débit. Face à la saturation des spectres radiofréquences, la technologie Light Fidelity (Li-Fi), qui repose sur l’utilisation de la lumière visible pour la transmission de données, s’impose comme une alternative prometteuse au Wi-Fi traditionnel. Contrairement aux réseaux sans fil basés sur les ondes radio, le Li-Fi exploite le spectre lumineux, offrant ainsi une capacité de transmission largement supérieure [1].

Le Li-Fi repose sur des sources lumineuses telles que les diodes électroluminescentes (LED) ou des lasers pour la transmission de données, et utilise la modulation de lumière pour encoder l’ information. Cette technologie permet des vitesses de transmission pouvant atteindre jusqu’à 1 Gb/s, et tire profit de la vaste bande passante disponible dans la lumière visible, estimée à 2600 fois plus grande que celle des ondes radio [2],[3], sans interférer avec les dispositifs utilisant les radiofréquences [1],[2].

Lors de la communication par laser, les variations de luminosité ambiante empêchent la mise en place d’un seuil de détection fixe entre les bits forts et faibles (1,0). Cette problématique de l’ adaptabilité du système à l’environnement peut être particulièrement bloquante pour la réalisation d’un tel prototype. Il sera alors intéressant de mettre en place un système de détection automatique de ces états hauts et bas à postériori, à l’aide d’un algorithme de K-nn . Cet algorithme d’intelligence artificielle est en effet adapté pour les opérations de “clustering”, permettant la classification des bits [4].

Pour limiter les erreurs occasionnelles, la méthode de Hamming [5] joue un rôle crucial, assurant la fiabilité des transmissions. En effet, les signaux lumineux peuvent être perturbés par divers facteurs comme les interférences atmosphériques ou des obstacles accidentels. Ces perturbations peuvent entraîner des inversions de bits (0 devenant 1 et inversement), compromettant l’intégrité du message reçu. Grâce au code de Hamming, il est possible non seulement de détecter ces erreurs, mais aussi de les corriger automatiquement si une seule erreur de bit s’est produite [6].

Dans un objectif de miniaturisation et de portabilité du matériel, les codes mis en place doivent avoir une complexité minimale, pouvant ainsi s’exécuter sur des microcontrôleurs tout en ralentissant le moins possible le traitement de l’information. Pour augmenter la vitesse de transmission (émission comme réception) du signal, il est également crucial de choisir avec précision les composants électroniques utilisés (transistors, phototransistors/photodiodes [7]), les plus adaptés pour le transfert de données.

En outre, cette technologie assure un niveau de sécurité accru, car la lumière visible ne traverse pas les murs et ne peut être captée qu’à proximité de la source lumineuse, rendant ainsi les transmissions moins vulnérables aux interceptions à distance [8].

Cependant, bien que le Li-Fi soit particulièrement adapté aux transmissions de données à courte portée (généralement de quelques mètres à quelques dizaines de mètres), il présente certaines limitations liées à la nécessité d’une ligne de vue entre l’émetteur et le récepteur. Cette contrainte limite son utilisation dans des environnements extérieurs ou dans des situations où des obstacles peuvent bloquer la transmission. À cet égard, la communication par laser, qui repose sur des principes similaires au Li-Fi, permet d’élargir la portée des transmissions jusqu’à des distances de 100 mètres ou plus, tout en maintenant un haut débit de données [3].

Dans l'objectif d'étudier la communication par laser et ses limites, nous réaliserons un dispositif capable d'émettre une information modulée à une vitesse de transmission satisfaisante, ainsi qu'un système en mesure de recevoir cette information à une distance de l'ordre de la centaine de mètres, tout en assurant la bonne qualité de l'information sur le lieu de réception.

Problématique retenue

La technologie laser est-elle efficace pour communiquer sur de longues distances ? Comment limiter les erreurs présentes lors de la réception d’un signal binaire ? Quels sont les avantages qu’elle présente par rapport à l’utilisation de fibre optique ?

Objectifs du TIPE du candidat

1. Concevoir un système de réception, permettant de convertir un signal optique en signal numérique
2. Réaliser un dispositif capable de communiquer à l’échelle de la dizaine de mètres
3. Créer un algorithme de traitement des données reçues et de correction des erreurs pour limiter

la perte d’information

4. Étudier les limitations techniques du prototype
5. Amélioration du système pour une utilisation à longue distance

Références bibliographiques (ÉTAPE 1)

[1] LOUIZA HAMADA : Conception d’une architecture supportant la technologie Li-Fi : Université de Haute Alsace - Mulhouse, 2022. Français. NNT : 2022MULH5026. tel-03955897
[2] JORGE GARCIA-MARQUEZ, SUAT TOPSU : Les communications par lumière visible : le Li-Fi : https://www.photoniques.com/articles/photon/pdf/2017/03/photon201786p22.pdf
[3] LUC CHASSAGNE : Technologie LiFi (Light Fidelity) : Laboratoire LISV EA4048, université de Versailles Saint-Quentin, Vélizy, France
[4] D.COOMANS, D.L.MASSART : Alternatives K-nn rules in supervised pattern recognition : Analytica chimica acta, 136 (1982)
[5] R.W.HAMMING : Error Detecting and Error Correcting Codes : The bell system technical journal, April 1950

[6] DR. ANIL KUMAR SINGH : Error Detection and Correction by Hamming Code : Department of Information Technology Jagran Institute of Management, City: Kanpur, U.P., India
[7] MALTI BANSAL, RAAGHAV RAJ MAIYA : Phototransistor: The Story So Far : Department of Electronics & Communication Engineering Delhi Technological University, Delhi-110042, India
[8] ALIN CAILEAN : Etude et réalisation d’un système de communications par lumière visible (VLC/LiFi). Application au domaine automobile. : Université de Versailles Saint-Quentin en Yvelines, 2014. Français. NNT : tel-01156468

DOT

[1] : Septembre -> Novembre : mise en place du système d'émission, implémentation des fonctions de conversion de données
[2] : Octobre : Étude des caractéristiques des photorésistances
[3] : Novembre -> Janvier : mise en place du premier système de réception, premiers essais et premiers blocages (erreurs de transmission, signaux erronés)
[4] : Janvier -> Février : mise en place du second système de communication, avec traitement différé de l'information
[5] : Février -> Mars : implémentation du code correcteur de Hamming, essais concluants à grande distance
[6] : Mars -> Avril : étude du caractère gaussien du faisceau laser, étude théorique de la distance limite d'émission

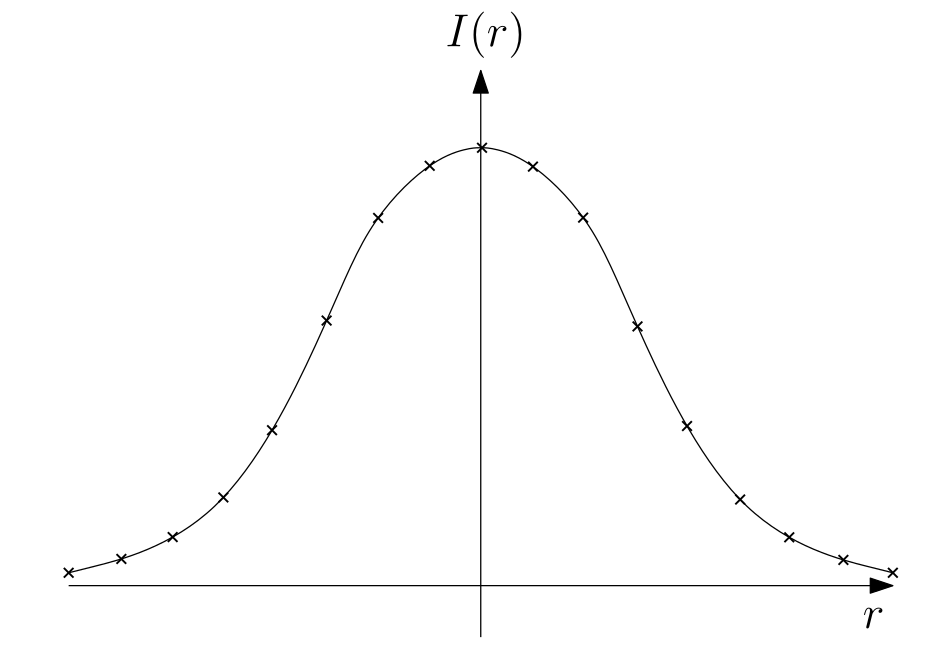
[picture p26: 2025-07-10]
theory/laser/pics/gaussian.png

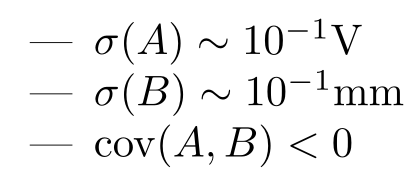
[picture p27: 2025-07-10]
theory/laser/pics/Screenshot from 2025-05-07 16-08-48.png

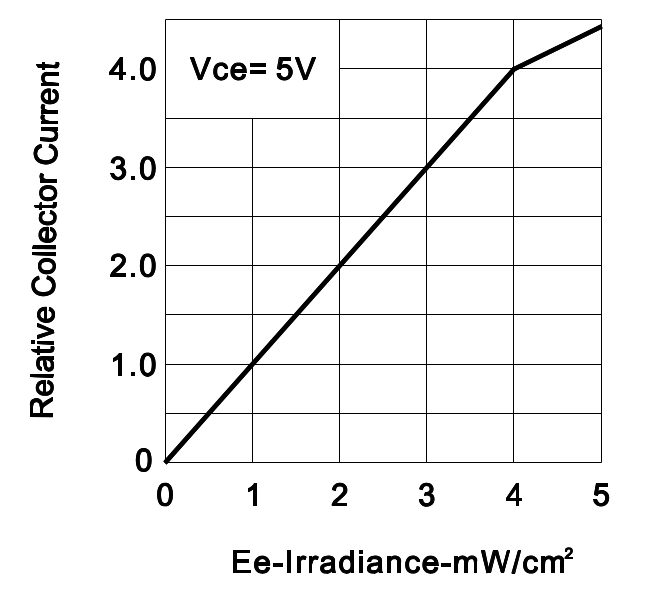
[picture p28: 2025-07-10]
theory/laser/pics/datasheet.png

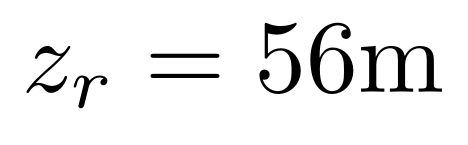
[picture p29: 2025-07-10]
theory/laser/pics/Screenshot from 2025-05-09 13-11-59.png

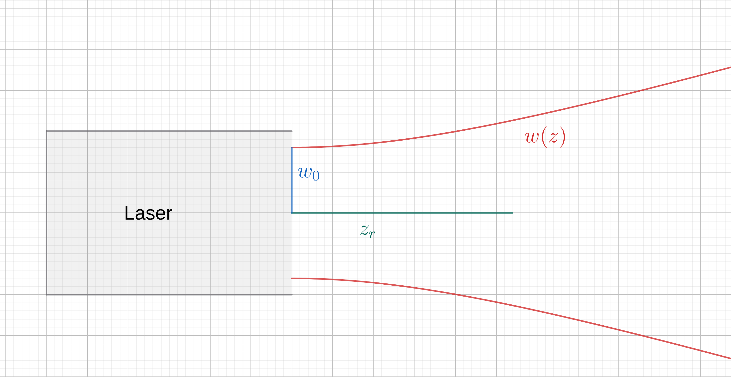
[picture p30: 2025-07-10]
theory/laser/pics/Rayleigh.png

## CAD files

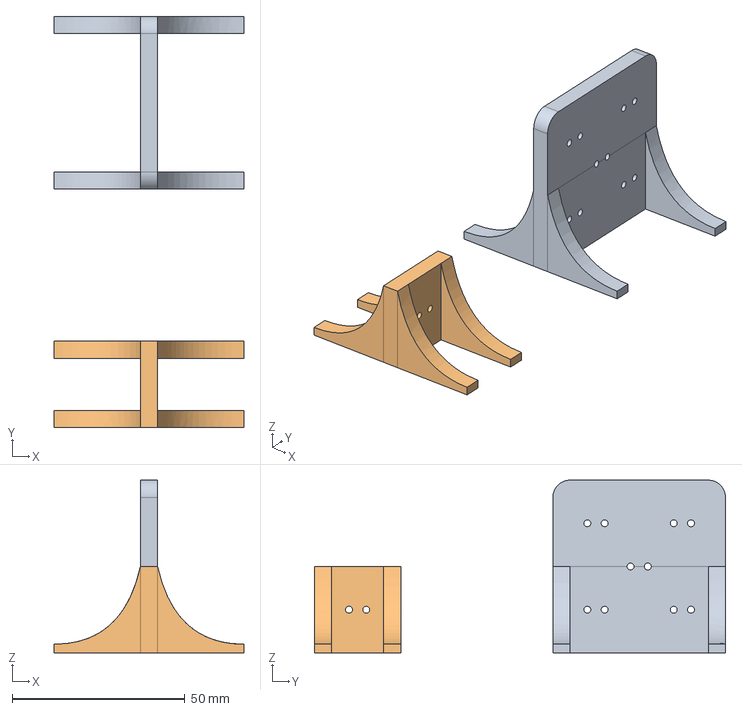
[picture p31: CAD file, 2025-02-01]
3D/stand.FCStd
55.0 x 119.0 x 50.0 mm
receptor
base

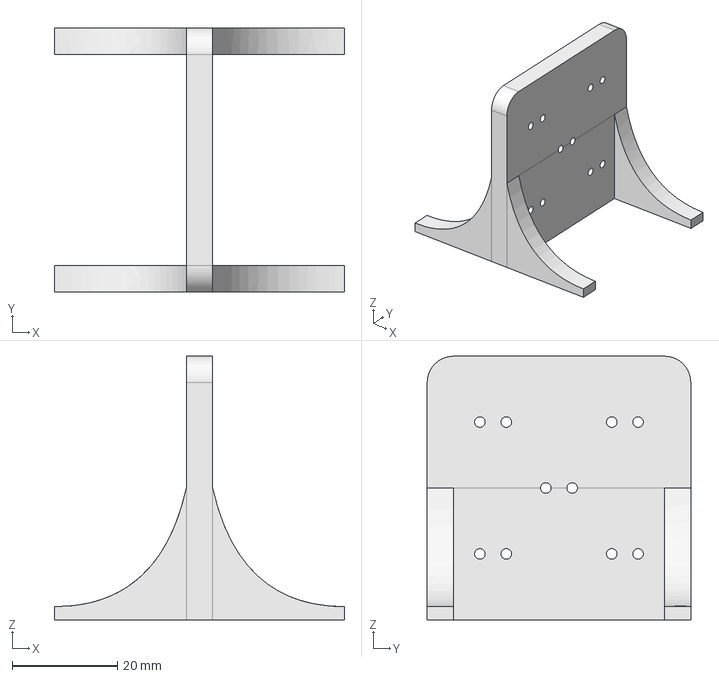
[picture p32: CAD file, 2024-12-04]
3D/stand-receptor.step
55.0 x 50.0 x 50.0 mm

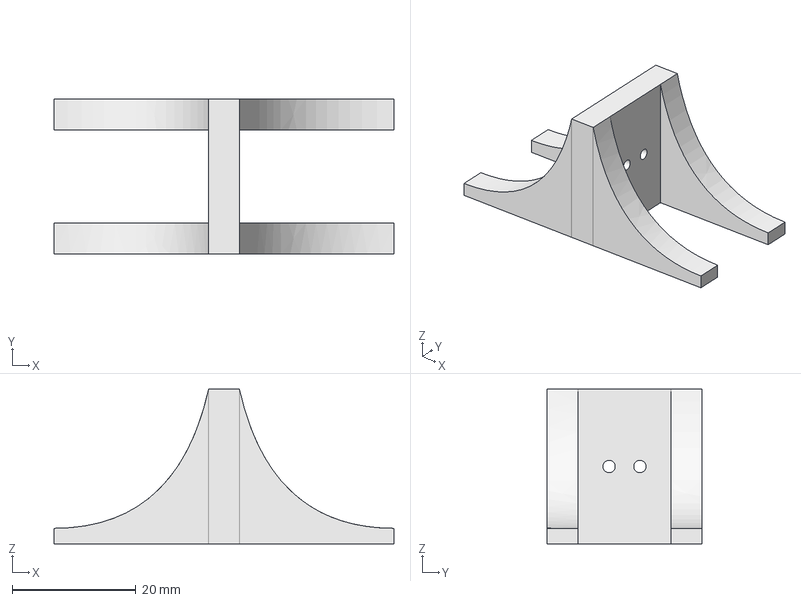
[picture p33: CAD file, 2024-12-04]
3D/stand-base.step
55.0 x 25.0 x 25.0 mm

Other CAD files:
3D/receptor (Meshed).stl
3D/base (Meshed).stl

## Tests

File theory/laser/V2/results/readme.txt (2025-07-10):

matrice prise dans le pire des cas pour la gaussienne

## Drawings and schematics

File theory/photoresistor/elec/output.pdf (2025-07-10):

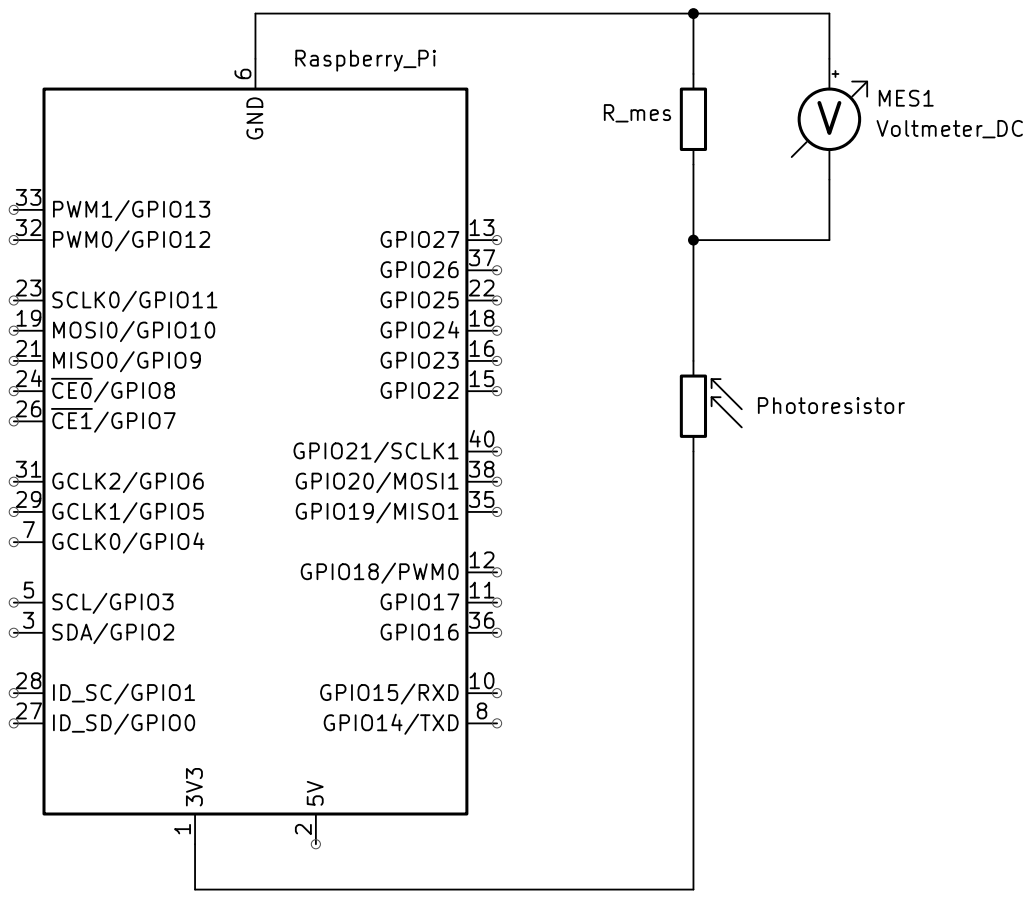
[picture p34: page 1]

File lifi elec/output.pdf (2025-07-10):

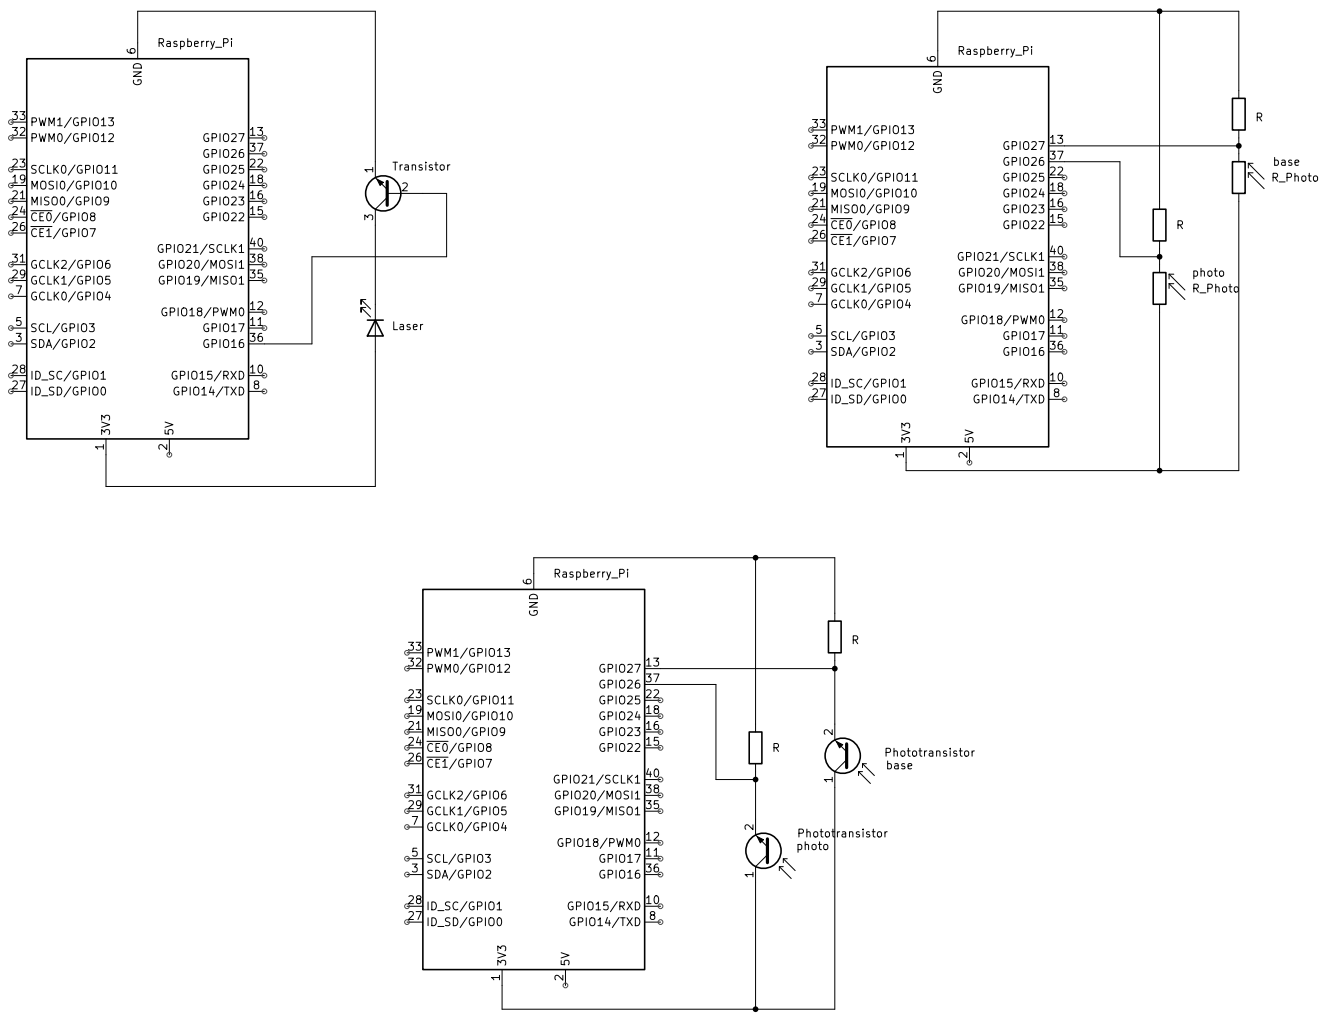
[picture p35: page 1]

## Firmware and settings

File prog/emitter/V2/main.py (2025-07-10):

from machine import Pin, PWM, ADC # type: ignore
from math import cos, pi
from time import sleep

def format_bis(entier, nb_bits):
    """
    Convertit un entier en binaire sur un nombre fixe de bits.

    Args:
        entier (int): L'entier à convertir.
        nb_bits (int): Le nombre de bits pour la représentation binaire.

    Returns:
        str: La représentation binaire de l'entier sur le nombre de bits spécifié.
    """
    # Convertit l'entier en binaire
    binaire = ""
    while entier > 0:
        binaire = str(entier % 2) + binaire
        entier //= 2

    # Ajoute des zéros de remplissage si nécessaire
    while len(binaire) < nb_bits:
        binaire = "0" + binaire

    # Tronque la chaîne si elle est trop longue
    if len(binaire) > nb_bits:
        binaire = binaire[-nb_bits:]

    return binaire

led = Pin('LED', Pin.OUT)
laser = Pin(16, Pin.OUT)

# Alphabet personnalisé codé sur 32 caractères (chacun pouvant ainsi être codé sur 5 bits)
alphabet = {'a':1,'b':2,'c':3,'d':4,'e':5,'f':6,'g':7,'h':8,'i':9,'j':10,'k':11,'l':12,
            'm':13,'n':14,'o':15,'p':16,'q':17,'r':18,'s':19,'t':20,'u':21,'v':22,'w':23,
            'x':24,'y':25,'z':26,' ':27,',':28,'.':29,'!':30,'?':31,"'":32}

# Inversion du dictionnaire pour obtenir une correspondance valeur -> lettre
tebahpla = {i: j for j, i in alphabet.items()}

def text_to_binary(message): #Entrée : str
    # Stocker le résultat
    binary_message = ""
    # Parcourir chaque caractère
    for c in message:
        if c in alphabet:
            # On attribue une valeur au cractère
            value = alphabet[c]
            # Convertir la valeur en binaire sur 5 bits
            binary_c = format_bis(value, 5)
            binary_message += binary_c
        else:
            print("Caractère '{c}' non supporté dans l'alphabet personnalisé.")
    return binary_message

def hamming_encode(str):
    reverse_str=str[::-1]
    n=len(str)
    k = 0
    while (2 ** k) < (n + k + 1): #Calcul du nombre k de bits de contrôle
        k += 1
    result = [0 for u in range (n+k)]
    i = 0
    for x in range(1,n+k+1): #Ajoute les bits d'informations aux bons emplacements
        if x & (x-1) != 0: #Vérifie si x n'est pas une puissance de 2, & est l'opérateur ET logique qui compare en binaire x et x-1.
            #L'idée avec x et x-1 est que si x est une puissance de 2, son binaire ne possède qu'un 1, x-1 inverse alors tous les bits.
            #Donc aucun des bits ne sera commun à x et x-1 donc "l'indicatrice" & ne s'allume jamais et on a 0.
            result[x-1]=reverse_str[i]
            i+=1
    bits_1=[]
    bin_bits_1=[]
    for x in range(n+k):
        if result[x] == '1':
            bits_1.append(x+1) #stock la position de tous les bits valant 1
    for x in bits_1:
        bin_bits_1.append(format_bis(x,k))
    parity=[0 for i in range(k)]
    for x in bin_bits_1:
        for i in range(len(x)):
            parity[i]+=int(x[::-1][i]) #Calcule la parité de chaque bit de contrôle
    for u in range(len(parity)):
        if parity[u]%2==1:
            result[(2**u)-1]='1' #Ajuste la valeur du bit de contrôle selon sa parité
    final=''
    for y in result[::-1]:
        final+=y
    return(final)

def emission(binary,f):
    binary2="1"+str(binary)+"1"
    for x in binary2:
        if x == "1":
            laser.high()
            sleep(1/f)
            laser.low()
        else:
            sleep(1/f)

#emission(101010101111110101010101010101010111,5)
#dire bonjour : emission(00010011110111001010011111010110010,5)

def text_to_light(message,f):
    return(emission(text_to_binary(message),f))

def text_to_light_hamming(message,f):
    return(emission(hamming_encode(text_to_binary(message)),f))

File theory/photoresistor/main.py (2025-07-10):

import numpy as np
import matplotlib.pyplot as plt

# res de mesure
R_mes = 215

I_global = []
U_photo_global = []
i_mes_global = []
E = np.array([0,0.49,0.98,1.47,1.96,2.45,2.94])

def store(I,U_R):
    U_photo = E - U_R
    i_mes = U_R / R_mes

    I_global.append(I)
    U_photo_global.append(U_photo)
    i_mes_global.append(i_mes)

### DATA ###
I = 0.07 # "intensité" lumineuse (éclairement lumineux)
U_R = np.array([0,0.007,0.015,0.022,0.03,0.037,0.045])
store(I,U_R)

I = 36
U_R = np.array([0,0.03,0.05,0.08,0.10,0.13,0.16])
store(I,U_R)

I = 98
U_R = np.array([0,0.038,0.077,0.11,0.15,0.19,0.23])
store(I,U_R)

I = 220
U_R = np.array([0,0.06,0.12,0.18,0.25,0.31,0.37])
store(I,U_R)

I = 348
U_R = np.array([0,0.069,0.137,0.20,0.27,0.34,0.41])
store(I,U_R)

I = 500
U_R = np.array([0,0.09,0.17,0.26,0.34,0.43,0.52])
store(I,U_R)

I = 670
U_R = np.array([0,0.11,0.21,0.32,0.43,0.54,0.65])
store(I,U_R)

I_global = np.array(I_global)
U_photo_global = np.array(U_photo_global)
i_mes_global = np.array(i_mes_global)

### FIRST PLOT ###
fig = plt.figure('Données brutes')
ax = fig.add_subplot(projection='3d')

for i in range(len(I_global)) :
    ax.plot(i_mes_global[i],U_photo_global[i], I_global[i], marker = '+', markersize=10)

plt.title('Lien entre intensité, tension et éclairement lumineux')
ax.set_xlabel('Intensité (A)')
ax.set_ylabel('Tension (V)')
ax.set_zlabel('Éclairement lumineux (lx)')
plt.tight_layout()
ax.grid()

### LINEAR REGRESSION ###
R = []
R_square = []

for i in range(len(I_global)) :
    vec = np.polyfit(i_mes_global[i], U_photo_global[i],1)

    R.append(vec[0])

    U_reg = i_mes_global[i]*vec[0]
    

    err_quadratique = np.sum((U_photo_global[i] - U_reg)**2)
    ecart_type = np.sum((U_photo_global[i] - np.mean(U_photo_global[i]))**2)

    R_square.append(1-err_quadratique/ecart_type)

R = np.array(R)

min_R_square = min(R_square)
min_R_square = round(min_R_square,3)

fig = plt.figure('Régression linéaire 1')

plt.plot(I_global,R, marker='+', linestyle='dotted', markersize=10)
plt.title(r'Lien entre éclairement lumineux et resistance, $R^2 = $' + str(min_R_square))
plt.xlabel('Éclairement lumineux (lx)')
plt.ylabel(r'Resistance ($\Omega$)')
plt.tight_layout()
plt.grid()

### LOI PHOTORESISTANCE ###
new_R = 1/R

vec = np.polyfit(I_global,new_R,1)

I_lin = np.linspace(min(I_global),max(I_global),100)

reg = vec[0]*I_lin + vec[1]

err_quadratique = np.sum((U_photo_global[i] - U_reg)**2)
ecart_type = np.sum((U_photo_global[i] - np.mean(U_photo_global[i]))**2)

R_square = (1-err_quadratique/ecart_type)
R_square = round(R_square,4)

fig = plt.figure('Régression linéaire 2')

plt.plot(I_global,new_R, marker='+', linestyle='dotted', markersize=10, label='Mesures')
plt.plot(I_lin,reg, color='orange', label='Régression')

plt.title(r'Régression linéaire, $R^2 = $' + str(R_square))
plt.xlabel('Éclairement lumineux (lx)')
plt.ylabel(r'1/R ($\Omega^{-1}$)')
plt.legend()
plt.tight_layout()
plt.grid()

R_reg = 1/reg

fig = plt.figure('Loi fonctionnement photorésistance')

plt.plot(I_global,R, marker='+', linestyle='dotted', markersize=10, label='Mesures')
plt.plot(I_lin,R_reg, color='orange', label='Régression')
plt.title('Loi de fonctionnement de la photorésistance')
plt.xlabel('Éclairement lumineux (lx)')
plt.ylabel(r'Résistance ($\Omega$)')
plt.legend()
plt.tight_layout()
plt.grid()

plt.show()

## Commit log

2024-10-23 3D models, photoresistors stands
    [base (Meshed).stl, receptor (Meshed).stl, stand.FCStd]
2024-12-04 3D models
    [stand-base.step, stand-receptor.step, stand.FCStd]
2025-02-01 change stand
    [stand.FCStd]
2025-02-01 small update
    [lifi.kicad_sch]
2025-07-10 deleting some files
    [fake_data.csv]
2025-07-10 updating schematics
    [lifi.kicad_sch]
2025-07-10 Theory about our laser
    [laser.kicad_pcb, laser.kicad_sch]
2025-07-10 Theory about photoresistors
    [photoresistor.kicad_pcb, photoresistor.kicad_sch]
2025-07-10 Updating all codes
    [1.csv, 2.csv, 3.csv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]
